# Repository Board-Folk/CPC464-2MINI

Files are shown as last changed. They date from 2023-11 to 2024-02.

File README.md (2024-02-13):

# CPC464-2MINI

A Mini CPC464

** Forever Work In Progress **

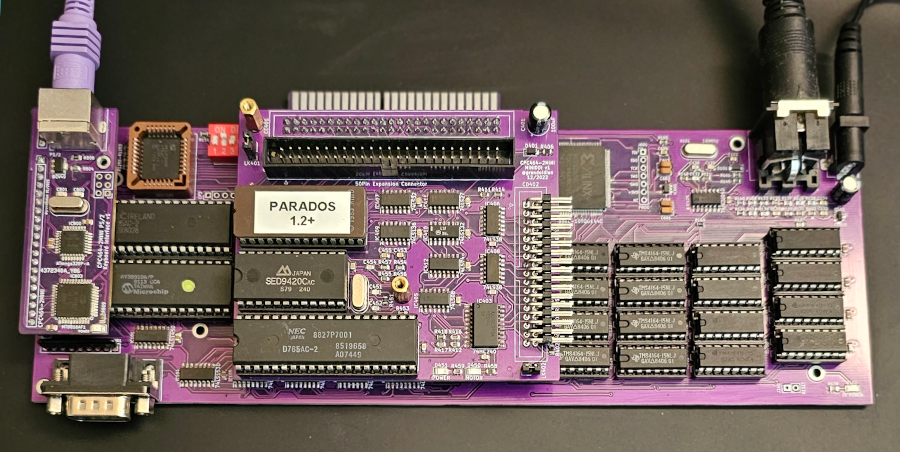
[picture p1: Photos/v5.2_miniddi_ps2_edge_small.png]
Built v5.2 Board with Edge Connector, PS/2 Interface and MINIDDI


A miniaturised version of Amstrad CPC464 second release with extensions. The main intention to try replace as much DIP with SMD as practically possible and have it as small as reasonably possible, with a standard board footprint that can later fit a 3D printed case that doesn't change between revisions. Latest versions, with everything on them, function as a 6128. This project is very much a private hobby project for now and is for fun and elements may lack any valid reason. It's been uploaded because of general interest.

More of the project may be dropped in here over time, kind of a place to sort out what's happened if you like, and what's working. There have been that many revisions/expansions it's been getting hard to keep track so it's nice to have a place. Things may be flagged as broken or untested where cautiously uploaded. 

## Revisions

The current version of the main board is v5.3, which uses the AMSGateArray Xilinx based gate array replacement linked to in the links section below. Thank you to all involved with that for this amazing project. Versions v4 and before require an original Amstrad 40010 or 40007 gate array (with adapter) for operation. Use of a 40007 somewhat impares operation especially regarding memory and other expansion compatiblity. Please see the readme file in each revisions folder for version specific information.

## Some Main Points

* Regulated 5V operation (centre terminal positive).
* The main board supports a full size original CPC464 Keyboard, **not** the later ones with the flat ribbon cables. An alternative PS/2 interface, which I expect most people will want to use is in the expansions folder.
* All releases still use 4164 RAM chips. Attempts at replacing these have so far failed due to the dual data bus (separate in and out pins are needed). Any help appreciated on this front, I can send schematics of my best guess so far which didn't work.
* All resistors and ceramic capacitors are 0805.
* Later revisions use PLCC32 instead of DIP28 for ROM due to space constraints.
* The v5 series board now also only supports the AY-3-8910 sound chip. Some earlier board supported the 8912, some both, the 8910 is much more readily available, also significantly cheaper. To note, you **can't** use an AY-3-8912 emulation board (well none that I've seen) with an Amstrad, they don't do the IO functions needed only sound.
* Some revisions of the board use a QFP44 Z80 not DIP40, including the latest revision, please check.
* Tape support changed for v5 on a different header needing an expansion card which hasn't been finished yet. Previous versions have a header compatible with the original 464 tape drive, and an adapter board for 3.5mm mono audio connections for a regular tape recorder/tapuino etc.
* There was a Mini-ITX version completed which included the disk interface (basically like a 6128), based on the pre-v5 boards in the Archive folder.
* As with original Amstrad CPCs of this generation, if you use the often more common A version AY-3-891x chip, e.g. AY-3-8910A you will need the SIP9 10K pullup resistor NR1 or your keyboard and joystick will not work correctly.
* All BOMs for now are just automatically generated iBOMs which only reflect the accuracy of the Kicad project they're from so be cautious.
* No, there's no HDMI port any of those other why didn't you things, feel free to add.

## Expansions

Expansion boards will be added over time. I'll try to place a big note in each readme which boards have not been tested. You'll probably want the Edge Connector, MINIDDI and PS/2 interfaces, but also check out the expansions folder.

Internal expansion boards stack vertically over a 2x25 pin header. Be warned, the rows for this are inverted from common secondary 6128 expansion cards that may already exist, though they typically need expansion adapter boards anyway for which there is one for this board. As things are at the moment each expansion card presents two headers for this to allow more options for stacking if you can't find the right socket/headers to stack directly. The primary expansions are:

* PS/2

An ATMEGA328/MT8816 based PS/2 adapter interface that mounts on the left of the board so you don't need an original keyboard.

* MINIEdge Edge Connector

It was decided that the main board wasn't going to include the original Amstrad edge connector as intended the expansions would be all neat and internal. The edge connector board solders on to the expansion connector on the base to provide the edge connector for traditional CPC expansions. This also has the virtue that the main board doesn't need ENIG, only this.

* MINIDDI

A version of the DDI-1 interface modified with the feelings of a 6128 and PPC640 to providing a 3.5" disk or Gotek drive interface. There's an adapter board for 3" drives.

** Check out the expansions folder for everything so far **

## Credits

Many thanks to Rob Taylor @peepouk and Chrissy @chris_jh with whom this project started, Richard Fry, Ian Stocks and the rest of the Board Folk Team. 
Special thanks to Noel Llopis for his amazing test ROM which has been invaluable for fixing buggy boards along the way.

## Links

  [AMSGateArray Gate Replacement Project](https://github.com/codedchip/AMSGateArray)<br>
  [Noel's Amstrad Diagnostics Test Suite](https://github.com/llopis/amstrad-diagnostics)

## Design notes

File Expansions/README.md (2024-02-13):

# CPC464-2MINI

CPC464-2MINI Expansions

* MINIEDGE

Edge connector for original expansion cards, for example the CPC Dandanator or whatever you might have.

* MINIPS/2

Atmega328 / MT8816 Based PS/2 Keyboard Adapter

* MINIDDI

3.5" Disk and Gotek Interface using the 765 disk controller and Epson SED. Standard PC floppy pinout. Adapter for 3" drives.

* MINIDOCK

Expansion to allow the installation of 6128 compatible expansion cards on the top of the system with additional 5V power injection.

* MINIRS232C

An updated version of the RS232C on a CPC464-2MINI Expansion board. Uses the MAX208 line driver / receiver with a 9 pin D-Sub instead

** On its way **

* MINIC2N

For the v5.3 board, a 9V system PSU and tape adapter to allow for the use of a Commodore C2N datasettes including both the C1530 and C1531 a well as 3.5mm Mic and Ear tape jacks for traditional cassette records and a header for an original CPC464 tape player as previously removed for v5. This works surprisingly well. Thanks to @PeepoUK for the idea.

** Untested and Unsorted **

* MINIUSIFACII

A USIFACII interface, though due to the chip shortage, this never got tested.

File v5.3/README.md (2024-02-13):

# CPC464-2MINI

CPC464-2MINI v5.3 Main Board

** Version 5 boards can't use an original Amstrad Gate array **

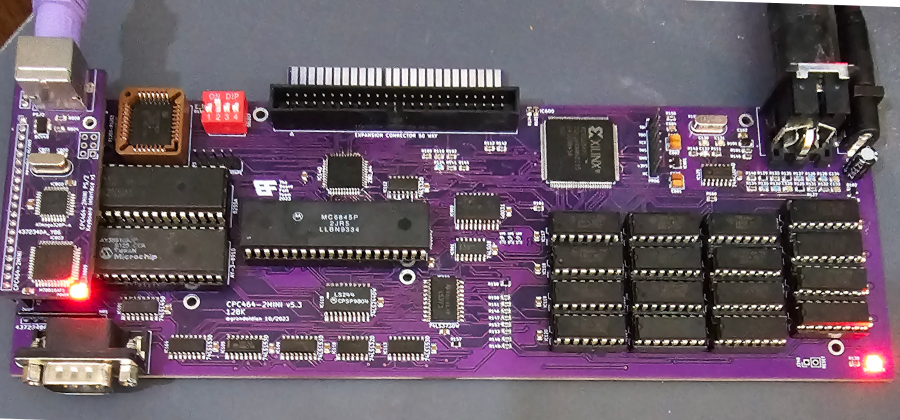
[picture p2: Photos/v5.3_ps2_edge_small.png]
Built v5.3 Main Board with PS/2 Keyboard Adapter


# Main points for this release

* AMSGateArray Xilinx based Gate Array. Needs skills.
* 128K RAM
* SMD 40031 GAL required for 128K operation
* QFP44 Z80 CPU
* AY-3-8910 Sound/IO Only
* PLCC32 ROM with switch selectable banking

# BOM

iBOM can be found in BOM folder.

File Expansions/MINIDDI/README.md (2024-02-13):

# MINIDDI

3.5" Disk and Gotek Interface using the 765 disk controller and Epson SED.

# Main points 

* Based on the DDI-1 with modifications for the Epson SED (as found in the 6128).
* This works with standard 3.5" PC Drives, and Goteks having borrowed slight changes from the PPC640.
* Adapter in the Extras folder for use with 3" drives.
* This hasn't really changed since the first release since it works so well. Might need a tidy up.
* More information to follow

# BOM

iBOM can be found in BOM folder.

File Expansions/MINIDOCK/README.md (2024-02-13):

# CPC464-2MINI Mini Dock

Docking board to allow the connection of vertical 6128 expansions on top.

# Main points 

* Only really proven with 6128 RAM Expansions
* Straight means same as the main board expansion pinout, inverted for 6128 expansion cards.
* Also provides additional power injection which may be required.
* Needs more testing.

# BOM

iBOM can be found in BOM folder.

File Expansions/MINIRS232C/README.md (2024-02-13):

# CPC464-2MINIRS232C v2

A CPC464-2MINI version of the original Amstrad RS232C adapter modified with an updated line driver / receiver and 9 pin D-Sub. Needs an original or Honeysoft Commstar ROM to operate.

# Main points 

* It uses an Z80 DART not the SIO/2
* The line driver / receiver is a MAX208 or compatible
* There was an original version with the original line driver and receiver which needs a voltage level converter which I may upload if needed. It's just easier to use the MAX208 version instead.
* More information to follow.

# BOM

iBOM can be found in BOM folder.

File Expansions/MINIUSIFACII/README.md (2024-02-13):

# CPC464-2MINIUSIFACII

A USIFACII board but due to the chip shortage, this never got tested.

# BOM

iBOM can be found in BOM folder.

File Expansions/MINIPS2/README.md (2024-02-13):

# MINIPS/2

Atmega328 / MT8816 Based PS/2 Adapter for the CPC464-2MINI

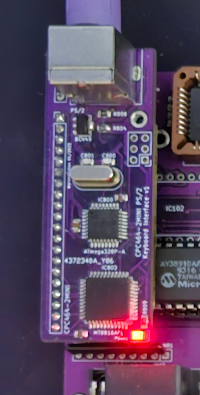
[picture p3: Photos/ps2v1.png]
Built PS/2 Interface


# Main points 

* Arduino Code found in the Arduino Folder. This needs uploading to the ATMega328.
* Print Screen pulls down !BUS to reset the system
* More notes to follow

# BOM

iBOM can be found in BOM folder.

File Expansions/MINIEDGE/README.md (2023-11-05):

# CPC464-2MINI-EDGE

Edge connector for original expansion cards, for example the CPC Dandanator or whatever you might have.

# Main points 

* This solders onto the base of the expansion header on the main board. Make sure you have long enough pins!
* This hasn't change since day dot.
* You might want to get this printed with ENIG.

# BOM

* There are no components on this board.

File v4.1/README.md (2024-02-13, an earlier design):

# CPC464-2MINI

CPC464-2MINI v4.1 Main Board

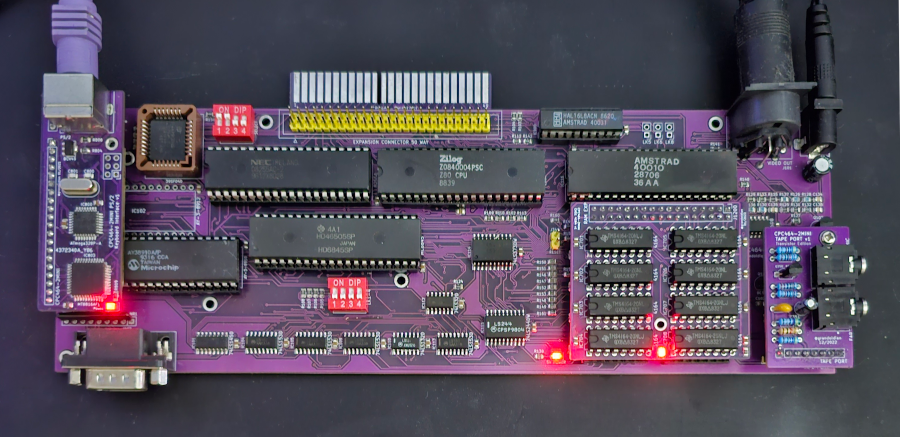
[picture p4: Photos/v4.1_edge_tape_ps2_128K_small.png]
Built CPC464-2MINI v4.1 Board


# Main points for this release

* Requires original Gate Array, 40010 or 40007 (with adapter). 40007 use impares operation.
* 128K RAM with upper 64K on expansion board
* 40031 DIP20 GAL required for 128K operation
* DIP40 Z80 CPU
* Both AY-3-8912 and AY-3-8910 Sound/IO chip sockets
* PLCC32 ROM with switch selectable banking
* DIP switch for ROM brand selection
* Original Tape Drive support, with adapter for 3.5mm mono audio connections

# BOM

iBOM can be found in BOM folder.

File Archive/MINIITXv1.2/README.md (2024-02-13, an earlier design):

# CPC464-2MINIITX v1.2

This ended up as a side project to try combine a few things, and well, to see if it fits. This last release works well anyway. It needs a 40010 though or Xilinx with an adapter board, which can sit over the RAM area.

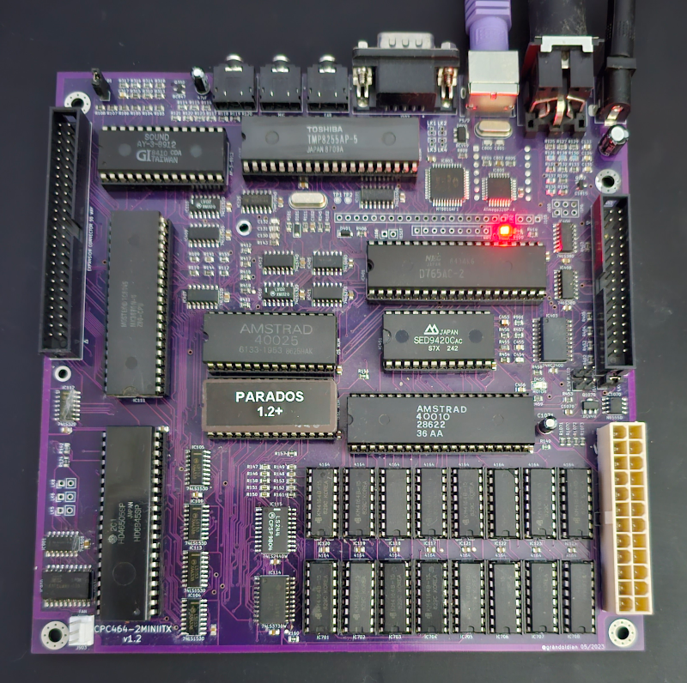
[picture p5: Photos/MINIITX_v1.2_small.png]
Built CPC464-2 MiniITX v1.2 Board


# Includes

* Disk Interface
* PS/2 Interface
* PIN headers for the other USB Keyboard project (which uses a SEEDUINO) that isn't published anywhere yet.
* Regular CPC464-2MINIITX Expansion slot, but sideways

# Main points 

* DIP40 Z80
* DIP28 ROMs
* AY-3-8912 Sound / IO
* 128K on board requiring the SMD 40031 GAL.
* ATX Power and Switch Latch or 5V DC Jack
* 3.5mm Mono Audio Tape Interface

# BOM

iBOM can be found in BOM folder.

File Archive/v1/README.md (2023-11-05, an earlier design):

# CPC464-2MINI v1

Uploaded for posterity and reference. The original second version of the CPC 464 on a board in the MINI size. 64K Only.

Please see the CPC-40007Adapter board in the v4 Extras folder if you want to use an original Amstrad 40007 Gate Array with this.

# BOM

iBOM can be found in BOM folder.

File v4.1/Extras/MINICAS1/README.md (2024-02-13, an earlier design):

# CPC464-2MINICAS1

Upper 64K Board for the CPC464-2MINI v4

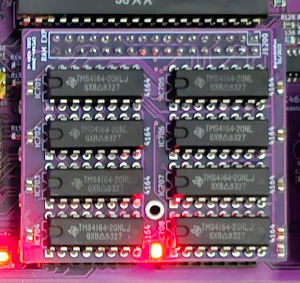
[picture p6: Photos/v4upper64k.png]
Upper 64K of RAM for v4.1


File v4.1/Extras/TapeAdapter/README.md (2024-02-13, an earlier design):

# CPC464-2MINI Tape Adapter

Tape Adapter for v4 and below revision CPC464-2MINI boards. This does not fit v5, that's to follow.

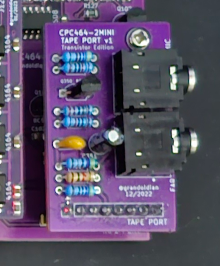
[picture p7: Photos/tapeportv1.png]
Built Tape Adapter


# Main points 

* This version uses a transistor and slight current limiting to allow you to plug in a standard tape recorder or Tapduino. It mounts on the tape header to the south east of the board instead of an original CPC464 tape player.

# BOM

iBOM can be found in BOM folder.

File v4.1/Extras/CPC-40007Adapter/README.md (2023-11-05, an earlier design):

# CPC-40007Adapter

An adapter to plug an Amstrad 40007 Gate Array in to a 40010 Socket. It's not a great idea, but if you're stuck.

This is nothing to do with the CPC464-2MINI v5 board, which can't use an original gate array.

# Main points 

* There are many things fundamentally flawed in doing this, including broken addressing, for example it won't boot with a Dandanator and 128K.
* It might need long pins to get above other components on later CPC464-2MINI boards.
* Due to the old Ferranti process, this requires a second voltage and generates some heat.
* There might be some fundamental flaw that I've missed that causes bad things to happen.
* It uses an LM1117 instead of resistors for the second voltage required.

# BOM

iBOM can be found in BOM folder.

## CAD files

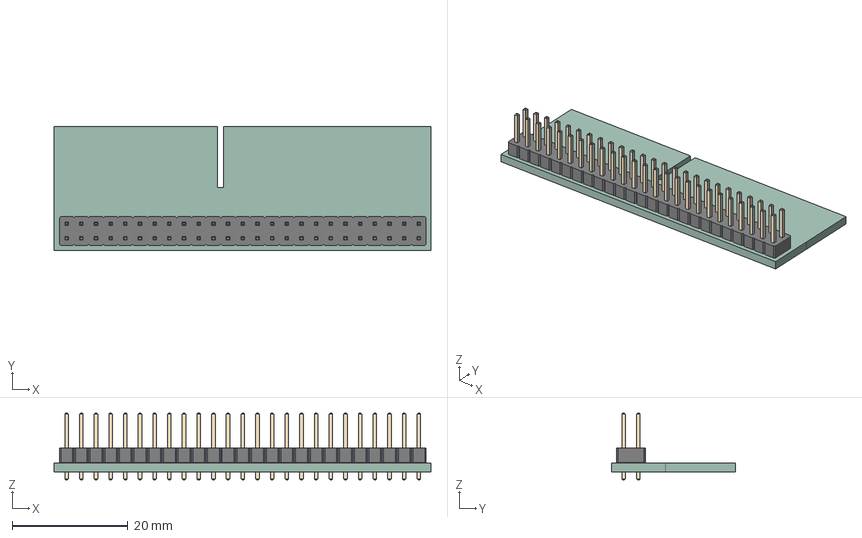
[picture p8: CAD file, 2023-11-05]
Expansions/MINIEDGE/Kicad/CPC464-2MINI-EDGE.step
65.2 x 21.4 x 11.5 mm
CPC464-2MINI-EDGE PCB

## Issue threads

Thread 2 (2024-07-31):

Sound problem and a few other problems.

HtmlBosss, 2024-07-31:
Hello, I assembled a few PCBs in version 5.3.

1) I have a problem with AY sound.

I use AY-3-8910A or YM2149F but I can't get any sound. I always hear noise (literally noise) on the J103 stereo output after starting any game or software. Do you have the same?
Problem with sound and a few other problems.

2) How do you have the jumpers set on resistors R185-R188?

3) Can I replace transistor Q102 (C1815) with another transistor that has similar pinouts and parameters?

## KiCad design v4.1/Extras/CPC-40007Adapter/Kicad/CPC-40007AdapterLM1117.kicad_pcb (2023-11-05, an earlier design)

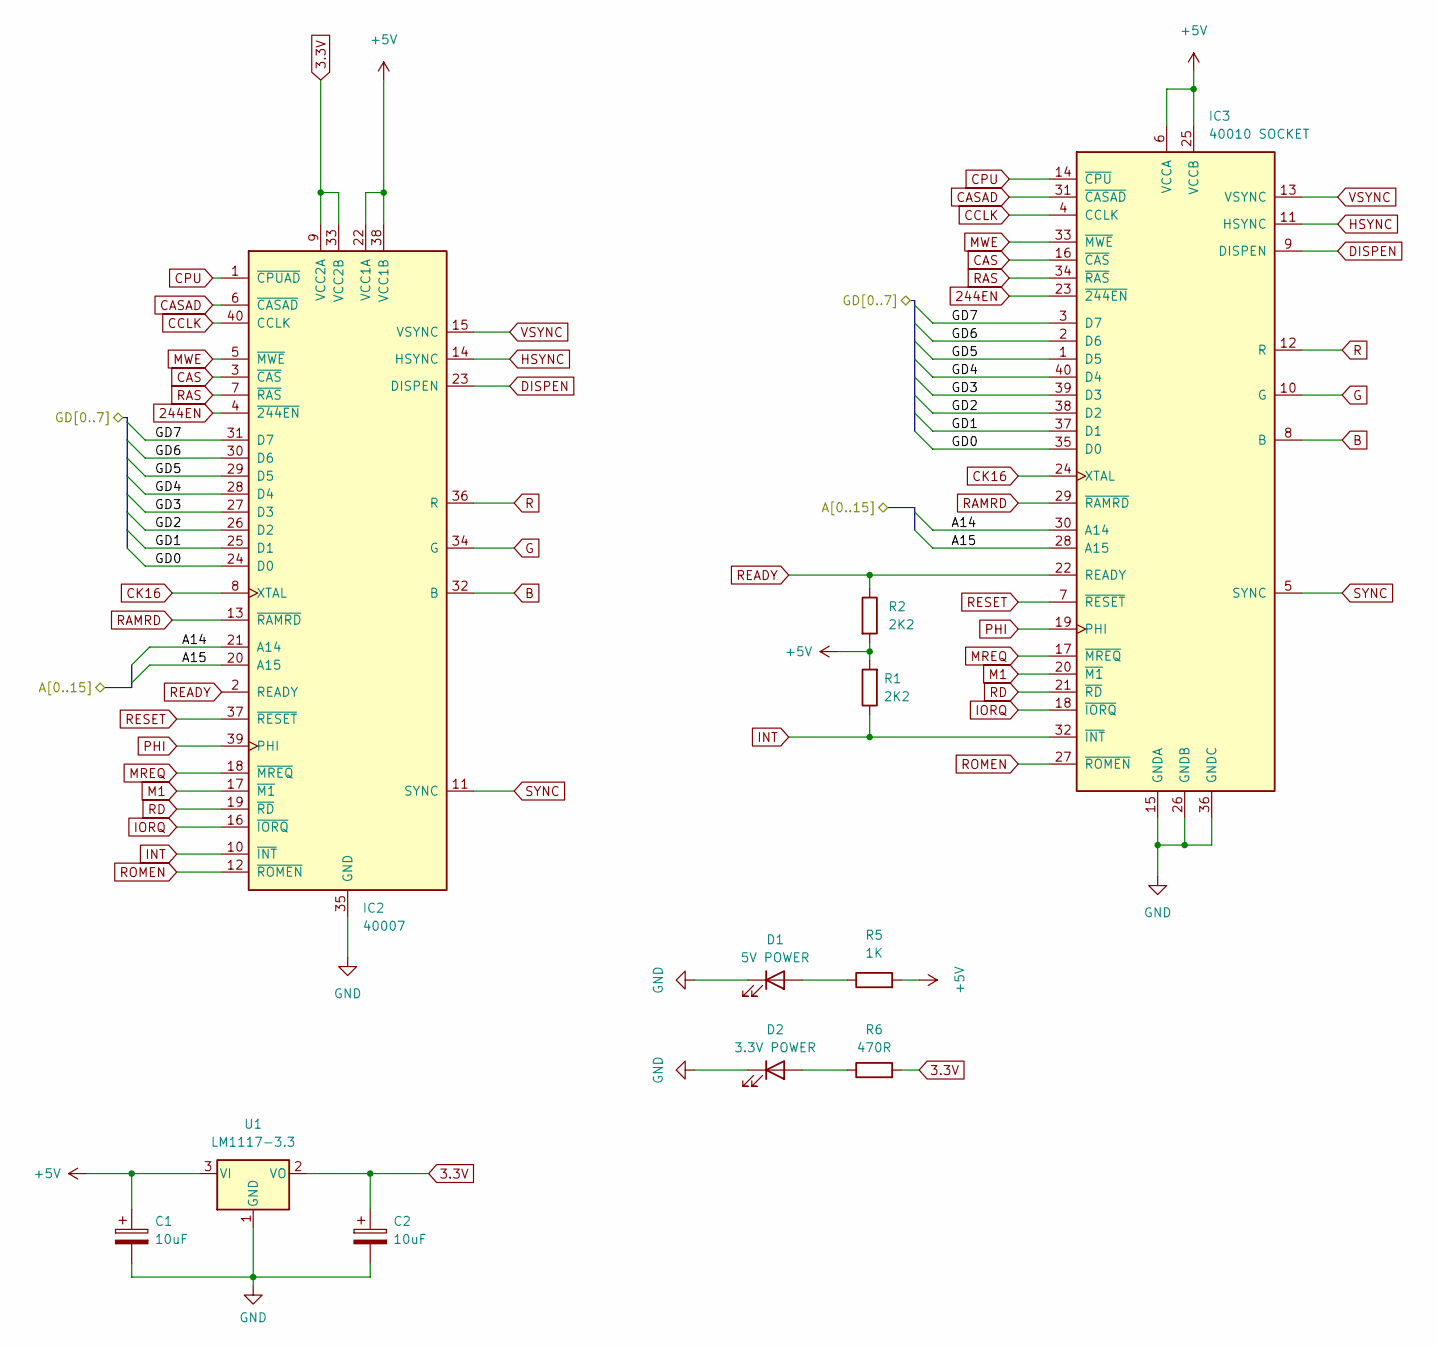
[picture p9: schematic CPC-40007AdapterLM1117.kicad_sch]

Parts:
C1, C2: 10uF; CP_EIA-3216-18_Kemet-A
D1: 5V POWER; LED_1206_3216Metric
D2: 3.3V POWER; LED_1206_3216Metric
IC2: 40007; DIP-40_W15.24mm_Socket_LongPads
IC3: 40010 SOCKET; 40010_Plug
R1, R2: 2K2; R_0805_2012Metric
R5: 1K; R_0805_2012Metric
R6: 470R; R_0805_2012Metric
U1: LM1117-3.3; SOT-223-3_TabPin2

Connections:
3.3V: C2.1, IC2.9 (VCC2A), IC2.33 (VCC2B), R6.2, U1.2 (VO)
244EN: IC2.4 (~244EN), IC3.23 (~244EN)
+5V: C1.1, IC2.22 (VCC1A), IC2.38 (VCC1B), IC3.6 (VCCA), IC3.25 (VCCB), R1.2, R2.2, R5.2, U1.3 (VI)
/A14: IC2.21 (A14), IC3.30 (A14)
/A15: IC2.20 (A15), IC3.28 (A15)
/GD0: IC2.24 (D0), IC3.35 (D0)
/GD1: IC2.25 (D1), IC3.37 (D1)
/GD2: IC2.26 (D2), IC3.38 (D2)
/GD3: IC2.27 (D3), IC3.39 (D3)
/GD4: IC2.28 (D4), IC3.40 (D4)
/GD5: IC2.29 (D5), IC3.1 (D5)
/GD6: IC2.30 (D6), IC3.2 (D6)
/GD7: IC2.31 (D7), IC3.3 (D7)
B: IC2.32 (B), IC3.8 (B)
CAS: IC2.3 (~CAS), IC3.16 (~CAS)
CASAD: IC2.6 (~CASAD), IC3.31 (~CASAD)
CCLK: IC2.40 (CCLK), IC3.4 (CCLK)
CK16: IC2.8 (XTAL), IC3.24 (XTAL)
CPU: IC2.1 (~CPUAD), IC3.14 (~CPU)
DISPEN: IC2.23 (DISPEN), IC3.9 (DISPEN)
G: IC2.34 (G), IC3.10 (G)
GND: C1.2, C2.2, D1.1 (K), D2.1 (K), IC2.35 (GND), IC3.15 (GNDA), IC3.26 (GNDB), IC3.36 (GNDC), U1.1 (GND)
HSYNC: IC2.14 (HSYNC), IC3.11 (HSYNC)
INT: IC2.10 (~INT), IC3.32 (~INT), R1.1
IORQ: IC2.16 (~IORQ), IC3.18 (~IORQ)
M1: IC2.17 (~M1), IC3.20 (~M1)
MREQ: IC2.18 (~MREQ), IC3.17 (~MREQ)
MWE: IC2.5 (~MWE), IC3.33 (~MWE)
unnamed: D1.2 (A), R5.1
unnamed: D2.2 (A), R6.1
PHI: IC2.39 (PHI), IC3.19 (PHI)
R: IC2.36 (R), IC3.12 (R)
RAMRD: IC2.13 (~RAMRD), IC3.29 (~RAMRD)
RAS: IC2.7 (~RAS), IC3.34 (~RAS)
RD: IC2.19 (~RD), IC3.21 (~RD)
READY: IC2.2 (READY), IC3.22 (READY), R2.1
RESET: IC2.37 (~RESET), IC3.7 (~RESET)
ROMEN: IC2.12 (~ROMEN), IC3.27 (~ROMEN)
SYNC: IC2.11 (SYNC), IC3.5 (SYNC)
VSYNC: IC2.15 (VSYNC), IC3.13 (VSYNC)

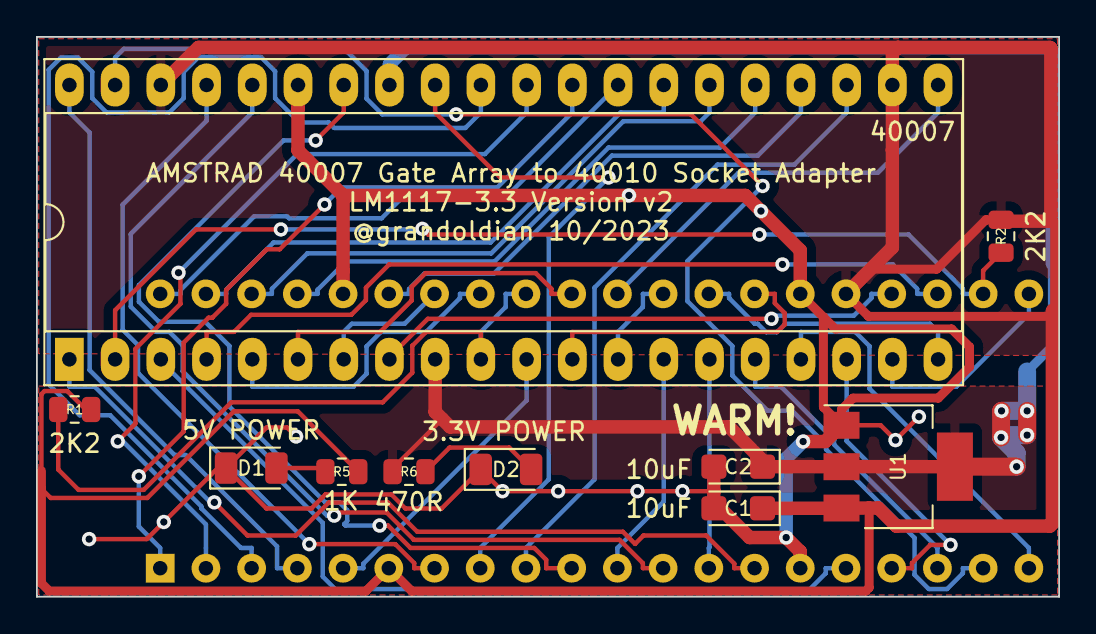
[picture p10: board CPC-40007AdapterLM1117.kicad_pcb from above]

Board: 2 copper layers, 56.8 x 31.1 mm, 11 parts (0 on the bottom side), 40 nets.

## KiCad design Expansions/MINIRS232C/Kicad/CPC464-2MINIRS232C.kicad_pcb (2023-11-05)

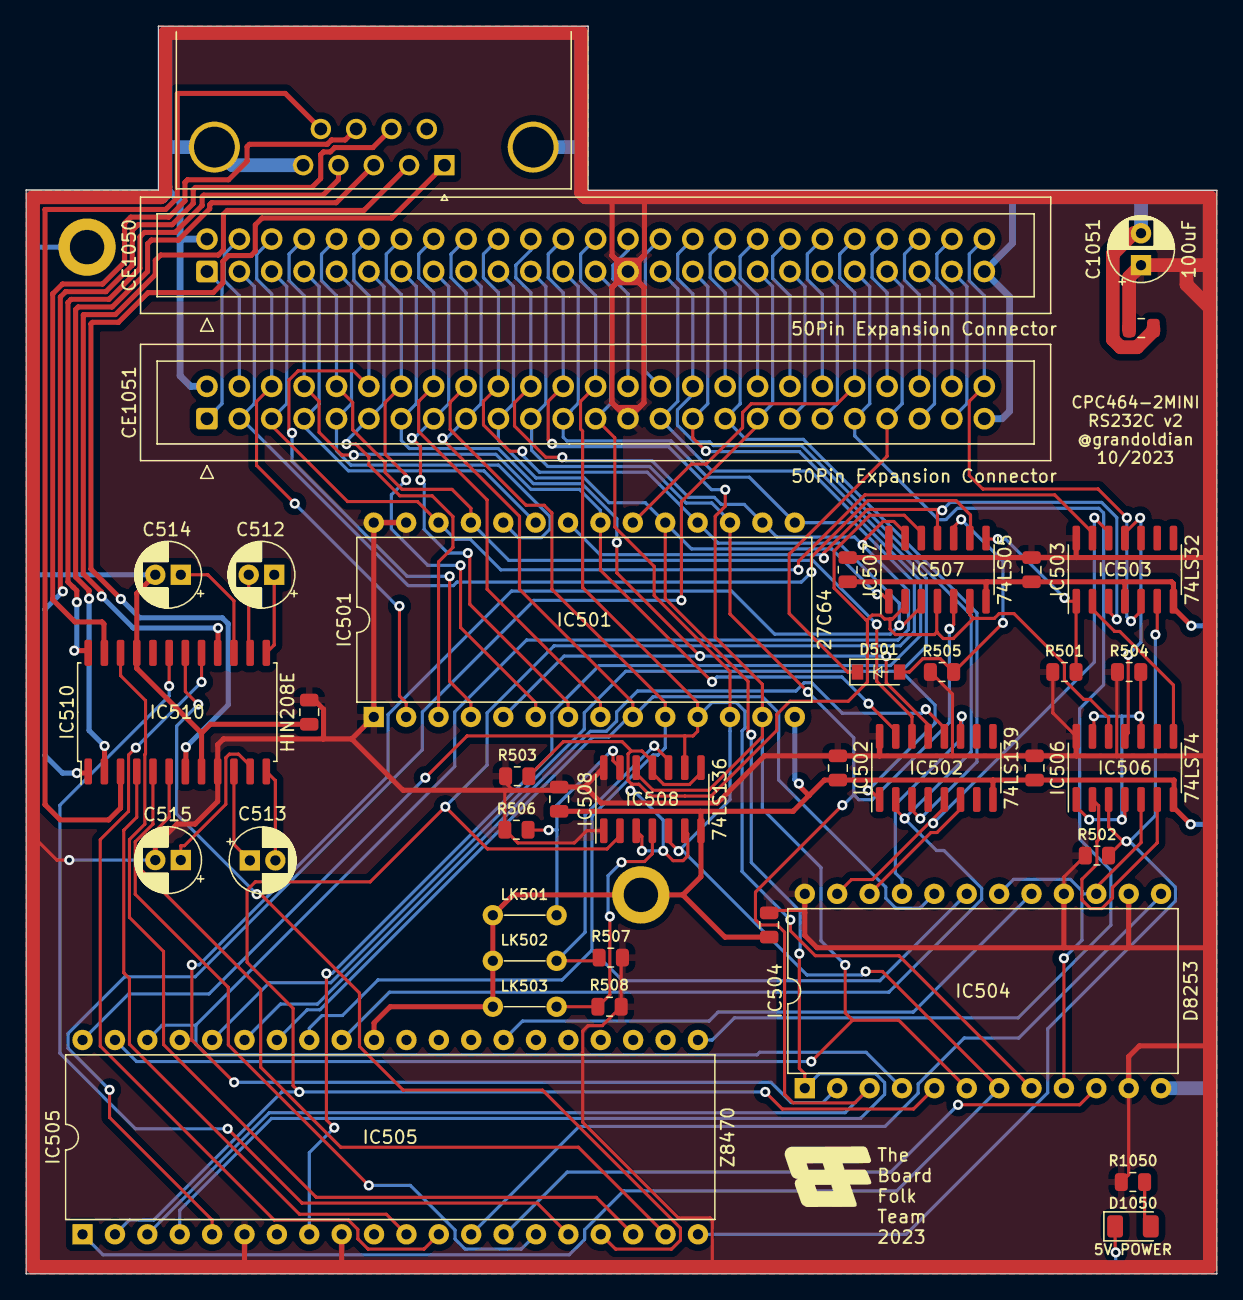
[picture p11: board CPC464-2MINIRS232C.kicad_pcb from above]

Board: 2 copper layers, 93.4 x 97.9 mm, 42 parts (0 on the bottom side), 90 nets.

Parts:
C502, C503, C504, C505, C506, C507, C508, C1050: 100nF; C_0805_2012Metric
C512, C513, C514, C515: 0.1uF; CP_Radial_D5.0mm_P2.00mm
C1051: 100uF; CP_Radial_D5.0mm_P2.50mm
CE1050, CE1051: 50Pin Expansion Connector; EXPANSION_IDC_ANONYMISED
D501: 1N4148; D101
D1050: 5V POWER; LED_1206_3216Metric
G1: Board Folk Logo; BF8
H1, H7: MountingHole; MountingHole_2.7mm_M2.5_ISO14580_Pad
IC501: 27C64; DIP-28_W15.24mm
IC502: 74LS139; SOIC-16_3.9x9.9mm_P1.27mm
IC503: 74LS32; SOIC-14_3.9x8.7mm_P1.27mm
IC504: D8253; DIP-24_W15.24mm
IC505: Z8470; DIP-40_W15.24mm
IC506: 74LS74; SOIC-14_3.9x8.7mm_P1.27mm
IC507: 74LS05; SOIC-14_3.9x8.7mm_P1.27mm
IC508: 74LS136; SOIC-14_3.9x8.7mm_P1.27mm
IC510: HIN208E; SOIC-24W_7.5x15.4mm_P1.27mm
LK501, LK502, LK503: Capacitor
PL505: DB9; DSUB-9_Male_Horizontal_P2.77x2.84mm_EdgePinOffset7.70mm_Hou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
R501, R503, R504, R1050: 1K; R_0805_2012Metric
R502, R505: 670R; R_0805_2012Metric
R506, R507, R508: 10K; R_0805_2012Metric

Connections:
+5V: C502.1, C503.1, C504.1, C505.1, C506.1, C507.1, C508.1, C515.2, C1050.1, C1051.1, CE1050.27, CE1051.27, IC501.1 (VPP), IC501.27 (~PGM), IC501.28 (VCC), IC502.16 (VCC), IC503.14 (VCC), IC504.11 (GATE0), IC504.14 (GATE1), IC504.16 (GATE2), IC504.24 (VCC), IC505.6 (IEI), IC505.9 (VCC), IC506.14 (VCC), IC507.14 (VCC), IC508.1, IC508.14 (VCC), IC510.9 (VCC), R501.1, R502.1, R503.1, R504.1, R505.1, R506.1, R507.1, R508.1, R1050.2
/AMSRS232C SM Edited/A0: CE1050.18, CE1051.18, IC501.10 (A0), IC504.19 (A0), IC505.33 (C/~D)
/AMSRS232C SM Edited/A1: CE1050.17, CE1051.17, IC501.9 (A1), IC504.20 (A1), IC505.34 (B/~A)
/AMSRS232C SM Edited/A2: CE1050.16, CE1051.16, IC501.8 (A2)
/AMSRS232C SM Edited/A3: CE1050.15, CE1051.15, IC501.7 (A3)
/AMSRS232C SM Edited/A4: CE1050.14, CE1051.14, IC501.6 (A4)
/AMSRS232C SM Edited/A5: CE1050.13, CE1051.13, IC501.5 (A5), IC502.13 (A1)
/AMSRS232C SM Edited/A6: CE1050.12, CE1051.12, IC501.4 (A6)
/AMSRS232C SM Edited/A7: CE1050.11, CE1051.11, IC501.3 (A7)
/AMSRS232C SM Edited/A8: CE1050.10, CE1051.10, IC501.25 (A8), IC502.14 (A0)
/AMSRS232C SM Edited/A9: CE1050.9, CE1051.9, IC501.24 (A9)
/AMSRS232C SM Edited/A10: CE1050.8, CE1051.8, IC501.21 (A10), IC502.15 (E)
/AMSRS232C SM Edited/A11: CE1050.7, CE1051.7, IC501.23 (A11)
/AMSRS232C SM Edited/A12: CE1050.6, CE1051.6, IC501.2 (A12)
/AMSRS232C SM Edited/A13: CE1050.5, CE1051.5, IC501.26 (A13), IC503.13
/AMSRS232C SM Edited/A14: CE1050.4, CE1051.4
/AMSRS232C SM Edited/A15: CE1050.3, CE1051.3, IC507.9
/AMSRS232C SM Edited/CTS_IN: IC505.18 (~CTSA), IC510.22 (R3OUT)
/AMSRS232C SM Edited/D0: CE1050.26, CE1051.26, IC501.11 (D0), IC504.8 (D0), IC505.40 (D0), IC508.9
/AMSRS232C SM Edited/D1: CE1050.25, CE1051.25, IC501.12 (D1), IC504.7 (D1), IC505.1 (D1), IC508.5
/AMSRS232C SM Edited/D2: CE1050.24, CE1051.24, IC501.13 (D2), IC504.6 (D2), IC505.39 (D2), IC508.12
/AMSRS232C SM Edited/D3: CE1050.23, CE1051.23, IC501.15 (D3), IC504.5 (D3), IC505.2 (D3), IC508.2
/AMSRS232C SM Edited/D4: CE1050.22, CE1051.22, IC501.16 (D4), IC504.4 (D4), IC505.38 (D4), IC507.13
/AMSRS232C SM Edited/D5: CE1050.21, CE1051.21, IC501.17 (D5), IC504.3 (D5), IC505.3 (D5), IC507.5
/AMSRS232C SM Edited/D6: CE1050.20, CE1051.20, IC501.18 (D6), IC504.2 (D6), IC505.37 (D6), IC507.3
/AMSRS232C SM Edited/D7: CE1050.19, CE1051.19, IC501.19 (D7), IC504.1 (D7), IC505.4 (D7), IC507.1
/AMSRS232C SM Edited/DCD_IN: IC505.19 (~DCDA), IC510.6 (R1OUT)
/AMSRS232C SM Edited/DTR_OUT: IC505.16 (~DTRA), IC510.19 (T3IN)
/AMSRS232C SM Edited/RI_IN: IC505.11 (~RIA), IC510.4 (R2OUT)
/AMSRS232C SM Edited/RTS_OUT: IC505.17 (~RTSA), IC510.18 (T2IN)
/AMSRS232C SM Edited/RX_OUT: IC505.15 (TxDA), IC510.5 (T1IN)
/AMSRS232C SM Edited/TX_IN: IC505.12 (RxDA), IC510.17 (R4OUT)
A100: CE1050.50, CE1051.50, IC503.5
BUS: CE1050.40, CE1051.40
BUSAK: CE1050.38, CE1051.38
BUSRQ: CE1050.37, CE1051.37
CURSOR: CE1050.46, CE1051.46
DCLK: IC503.6, IC505.20 (CLK), IC506.3 (C), R502.2
DSEL: IC502.12 (O0), IC505.35 (~CE)
EXP: CE1050.48, CE1051.48
GND: C502.2, C503.2, C504.2, C505.2, C506.2, C507.2, C508.2, C514.2, C1050.2, C1051.2, CE1050.2, CE1050.49, CE1051.2, CE1051.49, D1050.1 (K), H1.1, H7.1, IC501.14 (GND), IC502.8 (GND), IC503.4, IC503.7 (GND), IC504.12 (GND), IC505.31 (GND), IC506.7 (GND), IC507.7 (GND), IC508.7 (GND), IC510.8 (GND), IC510.21 (T4IN), LK501.2, LK502.2, LK503.2, PL505.0 (PAD), PL505.5
HALT: CE1050.34, CE1051.34
INT: CE1050.35, CE1051.35, IC505.5 (~INT)
IORQ: CE1050.31, CE1051.31, IC502.1 (E), IC505.36 (~IORQ)
LPEN: CE1050.47, CE1051.47
M1: CE1050.29, CE1051.29, IC505.8 (~M1)
MREQ: CE1050.28, CE1051.28
NMI: CE1050.36, CE1051.36
unnamed: D501.2 (A), IC507.10, R505.2
unnamed: D1050.2 (A), R1050.1
unnamed: IC502.11 (O1), IC504.21 (~CS)
unnamed: IC503.1, IC507.8, R501.2
unnamed: IC504.9 (CLK0), IC504.15 (CLK1), IC504.18 (CLK2), IC506.5 (Q)
unnamed: IC504.10 (OUT0), IC505.14 (~TxCA)
unnamed: IC504.13 (OUT1), IC505.13 (~RxCA)
unnamed: IC504.17 (OUT2), IC505.27 (~RxTxCB)
unnamed: IC506.2 (D), IC506.6 (~Q)
unnamed: IC506.1 (~R), IC506.4 (~S), IC506.10 (~S), IC506.13 (~R), R504.2
unnamed: IC503.11, IC506.11 (C)
unnamed: IC503.2, IC506.8 (~Q)
unnamed: C513.1, IC510.10 (C1+)
unnamed: C513.2, IC510.12 (C1-)
unnamed: C512.1, IC510.13 (C2+)
unnamed: C512.2, IC510.14 (C2-)
unnamed: C515.1, IC510.11 (V+)
unnamed: C514.1, IC510.15 (V-)
unnamed: IC508.13, LK501.1, R506.2
unnamed: IC508.10, LK502.1, R507.2
unnamed: IC508.4, LK503.1, R508.2
ODDEN: IC506.12 (D), IC507.2, IC507.4, IC507.6, IC507.12, IC508.3, IC508.6, IC508.8, IC508.11, R503.2
RAMDIS: CE1050.45, CE1051.45
RAMRD: CE1050.44, CE1051.44
RD: CE1050.32, CE1051.32, IC502.2 (A0), IC505.32 (~RD)
READY: CE1050.39, CE1051.39
RESET: CE1050.41, CE1051.41, IC505.21 (~RESET)
RFSH: CE1050.30, CE1051.30
ROMDIS: CE1050.43, CE1051.43, D501.1 (K)
ROMEN: CE1050.42, CE1051.42, IC501.20 (~CE)
RS_CTS: IC510.23 (R3IN), PL505.8
RS_DCD: IC510.7 (R1IN), PL505.1
RS_DTR: IC510.24 (T3OUT), PL505.4
RS_RI: IC510.3 (R2IN), PL505.9
RS_RTS: IC510.1 (T2OUT), PL505.7
RS_RX: IC510.2 (T1OUT), PL505.3
RS_TX: IC510.16 (R4IN), PL505.2
SOUND: CE1050.1, CE1051.1
WR: CE1050.33, CE1051.33, IC502.3 (A1)
~RARD: IC502.6 (O2), IC504.22 (~RD)
~RAWR: IC502.5 (O1), IC503.12, IC504.23 (~WR)
~ROMOE: IC501.22 (~OE), IC503.3, IC507.11

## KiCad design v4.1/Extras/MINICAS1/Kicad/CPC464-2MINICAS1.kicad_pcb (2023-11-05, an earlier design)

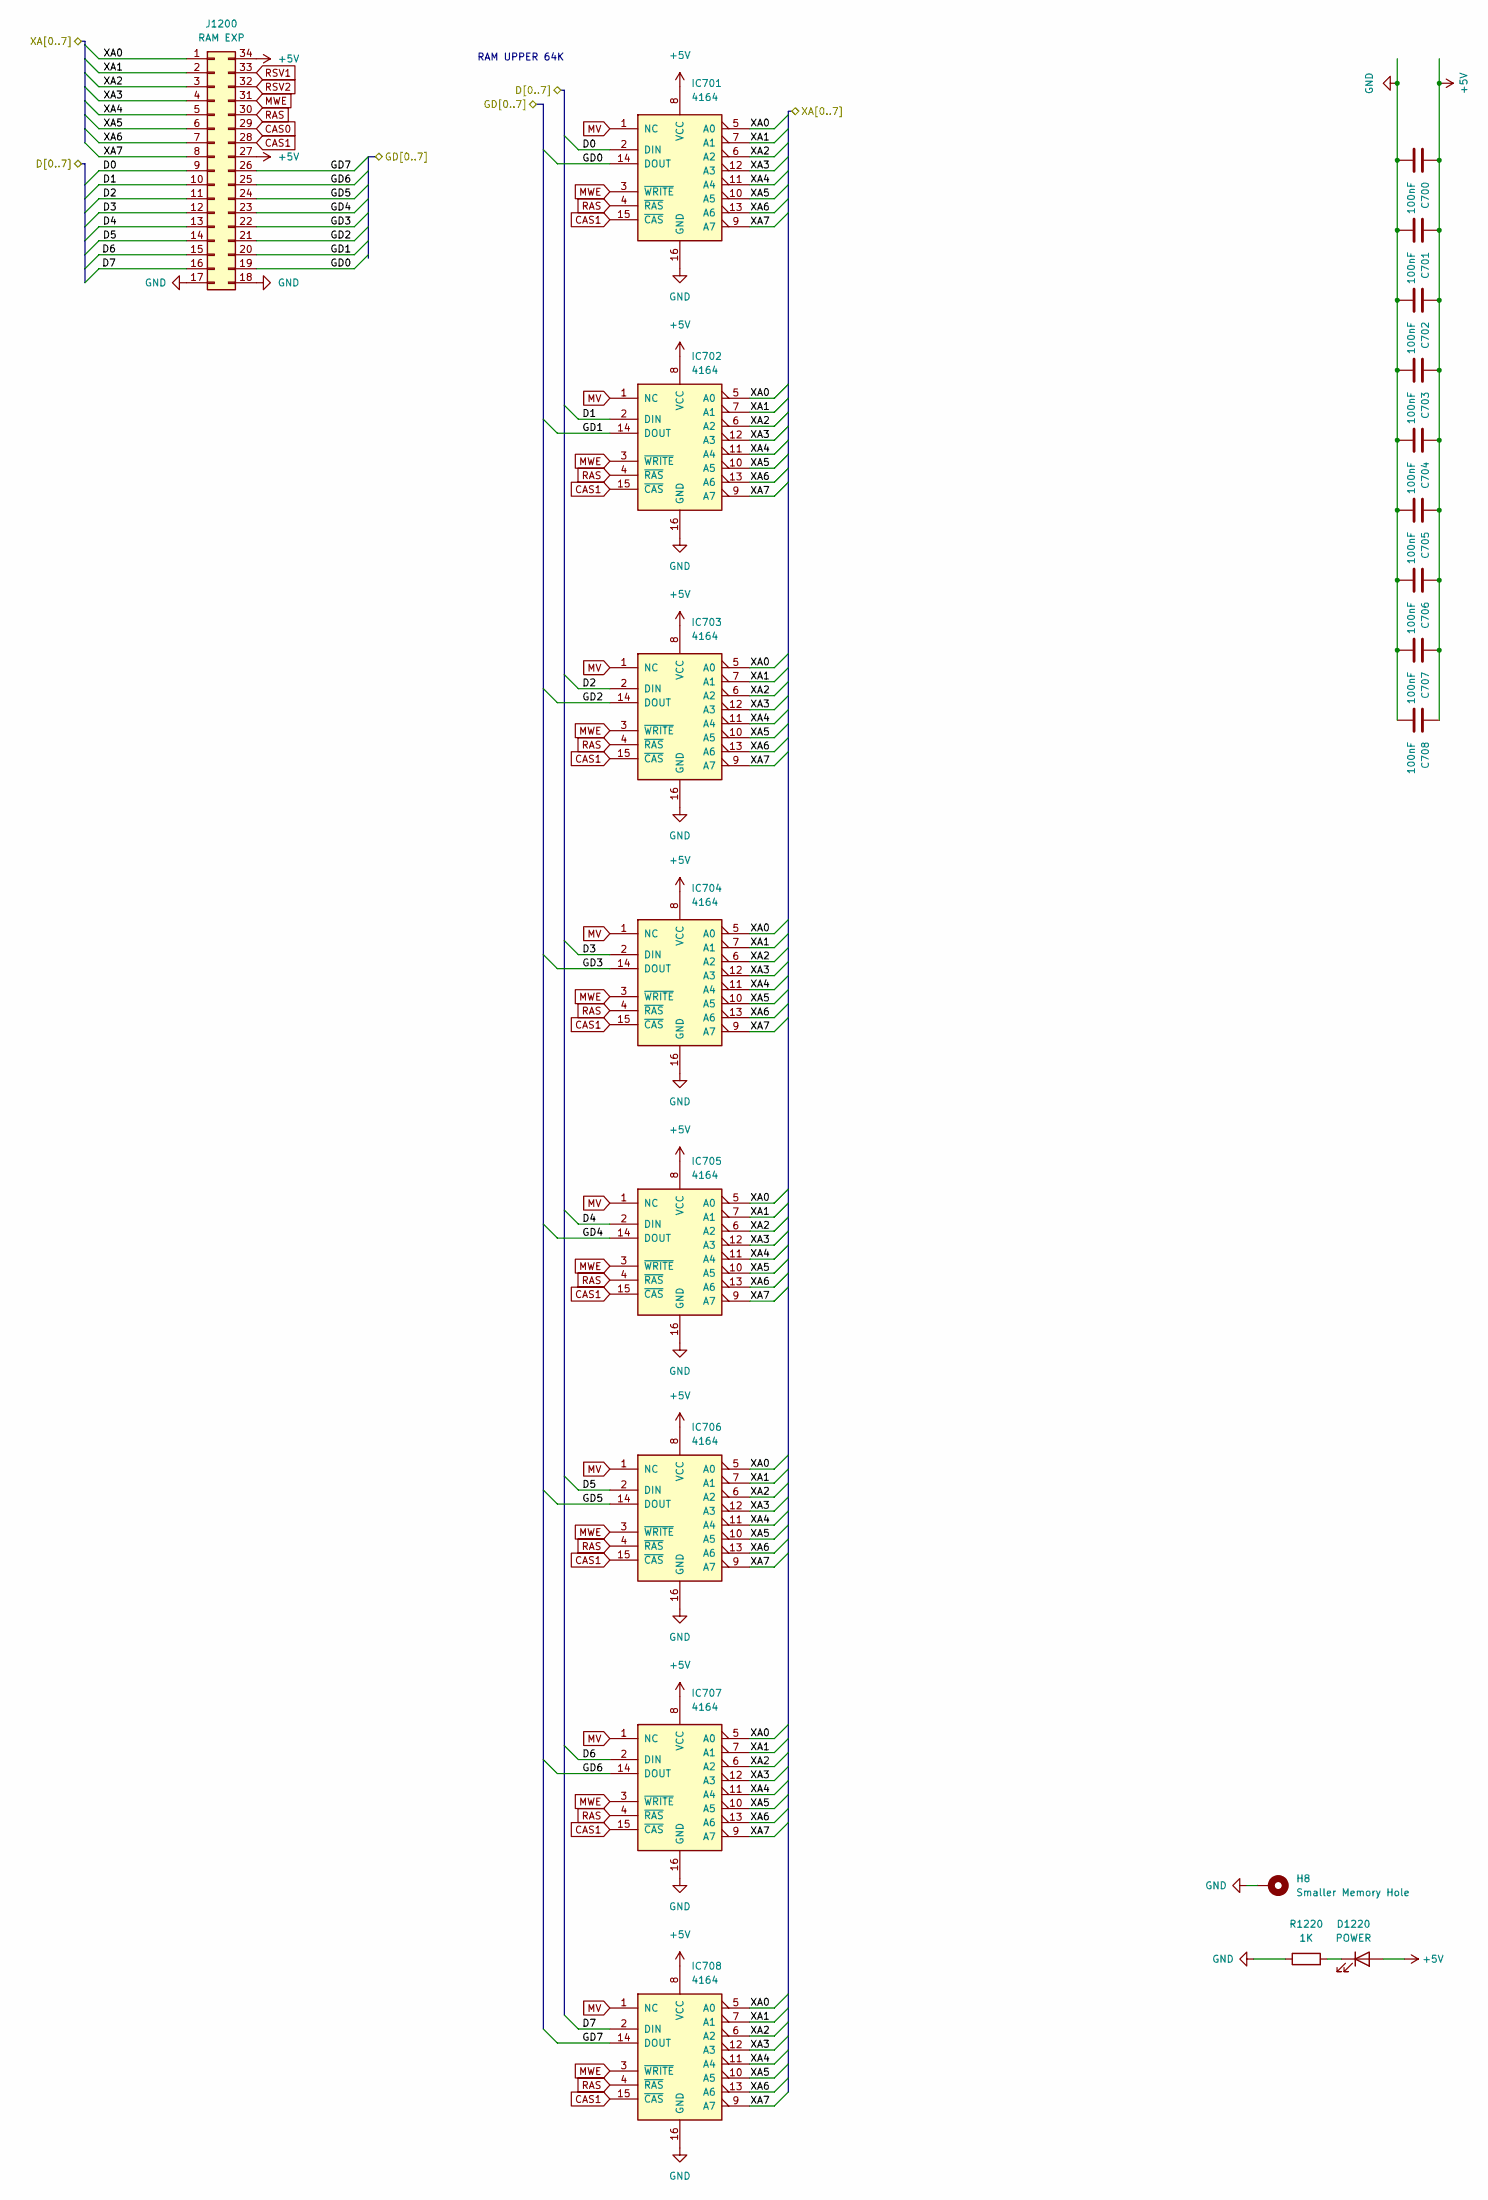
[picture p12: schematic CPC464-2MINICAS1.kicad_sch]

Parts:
C700, C701, C702, C703, C704, C705, C706, C707, C708: 100nF; C_0805_2012Metric; LCSC C49678
D1220: POWER; LED_1206_3216Metric
H8: Smaller Memory Hole; MountingHole_2.2mm_M2_DIN965_Pad
IC701, IC702, IC703, IC704, IC705, IC706, IC707, IC708: 4164; DIP-16_W7.62mm
J1200: RAM EXP; PinHeader_2x17_P2.54mm_Vertical
R1220: 1K; R_0805_2012Metric

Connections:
+5V: C700.1, C701.1, C702.1, C703.1, C704.1, C705.1, C706.1, C707.1, C708.1, D1220.2 (A), IC701.8 (VCC), IC702.8 (VCC), IC703.8 (VCC), IC704.8 (VCC), IC705.8 (VCC), IC706.8 (VCC), IC707.8 (VCC), IC708.8 (VCC), J1200.27, J1200.34
/D0: IC701.2 (DIN), J1200.9
/D1: IC702.2 (DIN), J1200.10
/D2: IC703.2 (DIN), J1200.11
/D3: IC704.2 (DIN), J1200.12
/D4: IC705.2 (DIN), J1200.13
/D5: IC706.2 (DIN), J1200.14
/D6: IC707.2 (DIN), J1200.15
/D7: IC708.2 (DIN), J1200.16
/GD0: IC701.14 (DOUT), J1200.19
/GD1: IC702.14 (DOUT), J1200.20
/GD2: IC703.14 (DOUT), J1200.21
/GD3: IC704.14 (DOUT), J1200.22
/GD4: IC705.14 (DOUT), J1200.23
/GD5: IC706.14 (DOUT), J1200.24
/GD6: IC707.14 (DOUT), J1200.25
/GD7: IC708.14 (DOUT), J1200.26
/XA0: IC701.5 (A0), IC702.5 (A0), IC703.5 (A0), IC704.5 (A0), IC705.5 (A0), IC706.5 (A0), IC707.5 (A0), IC708.5 (A0), J1200.1
/XA1: IC701.7 (A1), IC702.7 (A1), IC703.7 (A1), IC704.7 (A1), IC705.7 (A1), IC706.7 (A1), IC707.7 (A1), IC708.7 (A1), J1200.2
/XA2: IC701.6 (A2), IC702.6 (A2), IC703.6 (A2), IC704.6 (A2), IC705.6 (A2), IC706.6 (A2), IC707.6 (A2), IC708.6 (A2), J1200.3
/XA3: IC701.12 (A3), IC702.12 (A3), IC703.12 (A3), IC704.12 (A3), IC705.12 (A3), IC706.12 (A3), IC707.12 (A3), IC708.12 (A3), J1200.4
/XA4: IC701.11 (A4), IC702.11 (A4), IC703.11 (A4), IC704.11 (A4), IC705.11 (A4), IC706.11 (A4), IC707.11 (A4), IC708.11 (A4), J1200.5
/XA5: IC701.10 (A5), IC702.10 (A5), IC703.10 (A5), IC704.10 (A5), IC705.10 (A5), IC706.10 (A5), IC707.10 (A5), IC708.10 (A5), J1200.6
/XA6: IC701.13 (A6), IC702.13 (A6), IC703.13 (A6), IC704.13 (A6), IC705.13 (A6), IC706.13 (A6), IC707.13 (A6), IC708.13 (A6), J1200.7
/XA7: IC701.9 (A7), IC702.9 (A7), IC703.9 (A7), IC704.9 (A7), IC705.9 (A7), IC706.9 (A7), IC707.9 (A7), IC708.9 (A7), J1200.8
CAS0: J1200.29
CAS1: IC701.15 (~CAS), IC702.15 (~CAS), IC703.15 (~CAS), IC704.15 (~CAS), IC705.15 (~CAS), IC706.15 (~CAS), IC707.15 (~CAS), IC708.15 (~CAS), J1200.28
GND: C700.2, C701.2, C702.2, C703.2, C704.2, C705.2, C706.2, C707.2, C708.2, H8.1, IC701.16 (GND), IC702.16 (GND), IC703.16 (GND), IC704.16 (GND), IC705.16 (GND), IC706.16 (GND), IC707.16 (GND), IC708.16 (GND), J1200.17, J1200.18, R1220.1
MV: IC701.1 (NC), IC702.1 (NC), IC703.1 (NC), IC704.1 (NC), IC705.1 (NC), IC706.1 (NC), IC707.1 (NC), IC708.1 (NC)
MWE: IC701.3 (~WRITE), IC702.3 (~WRITE), IC703.3 (~WRITE), IC704.3 (~WRITE), IC705.3 (~WRITE), IC706.3 (~WRITE), IC707.3 (~WRITE), IC708.3 (~WRITE), J1200.31
unnamed: D1220.1 (K), R1220.2
RAS: IC701.4 (~RAS), IC702.4 (~RAS), IC703.4 (~RAS), IC704.4 (~RAS), IC705.4 (~RAS), IC706.4 (~RAS), IC707.4 (~RAS), IC708.4 (~RAS), J1200.30
RSV1: J1200.33
RSV2: J1200.32

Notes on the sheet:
RAM UPPER 64K

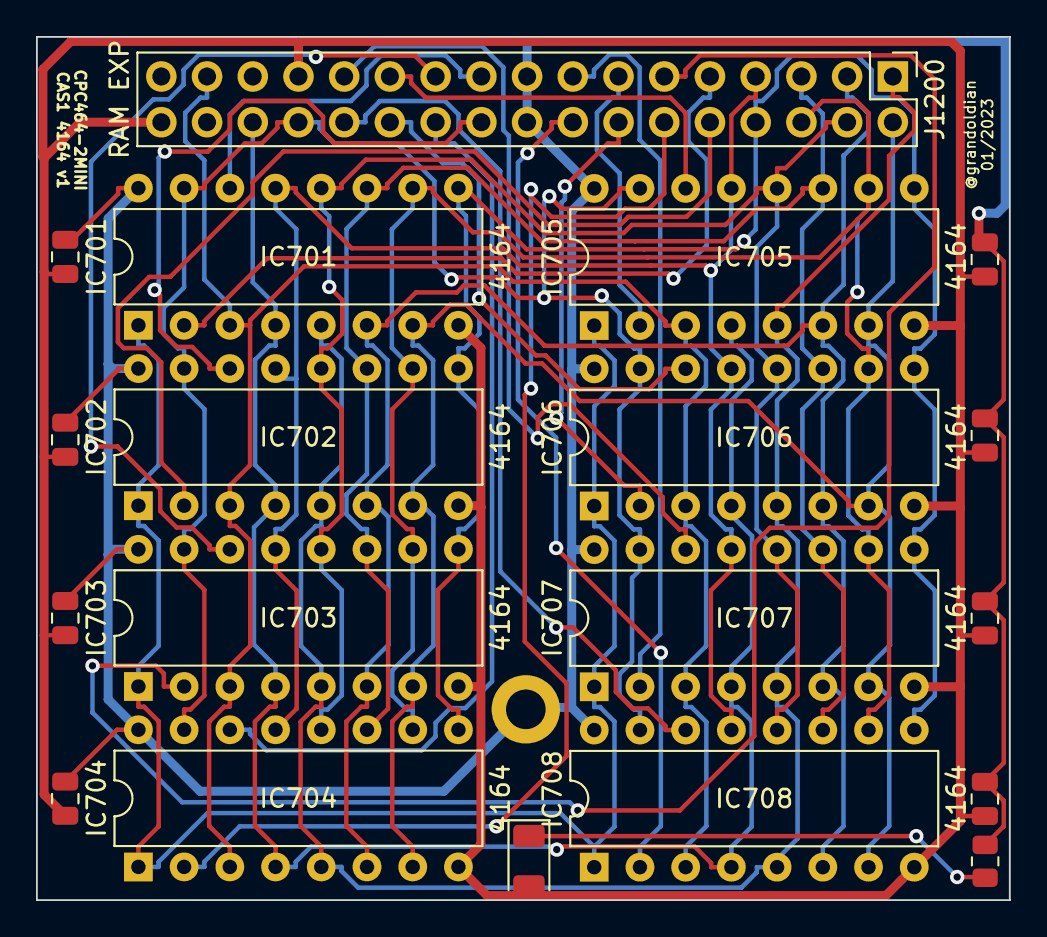
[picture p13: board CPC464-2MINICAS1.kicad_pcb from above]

Board: 2 copper layers, 54.1 x 48.0 mm, 20 parts (0 on the bottom side), 31 nets.

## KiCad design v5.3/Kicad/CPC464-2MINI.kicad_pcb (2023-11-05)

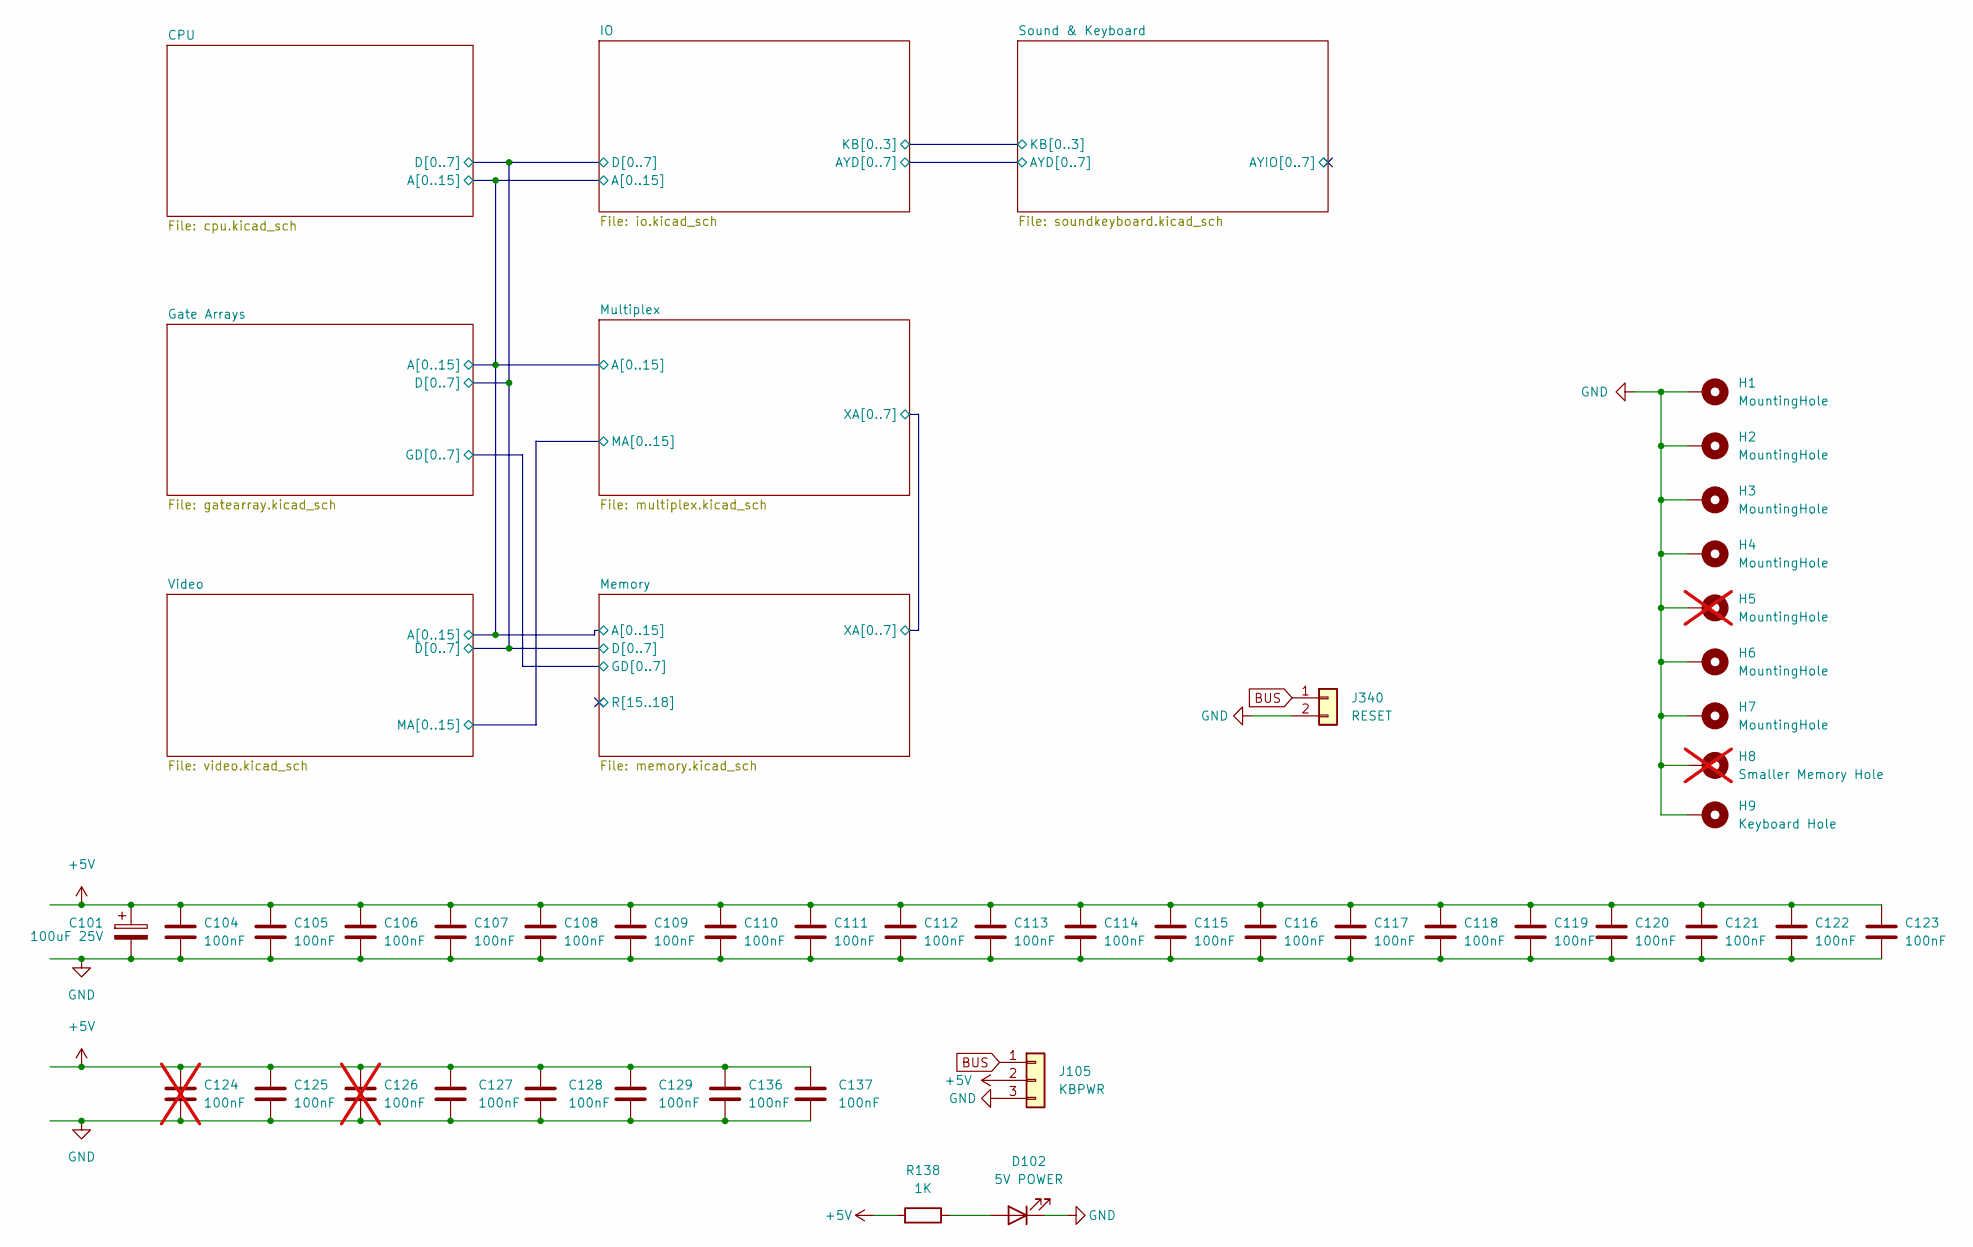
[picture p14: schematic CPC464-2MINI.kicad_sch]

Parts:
C101: 100uF 25V; CP_Radial_D5.0mm_P2.50mm
C104, C105, C106, C107, C108, C109, C110, C111, C112, C113, C114, C115, C116, C117, C118, C119, C120, C121, C122, C123, C125, C127, C128, C129, C136, C137: 100nF; C_0805_2012Metric; LCSC C49678
C124, C126: 100nF; C_0805_2012Metric; LCSC C49678; not fitted
D102: 5V POWER; LED_1206_3216Metric
H1, H2, H3, H4, H6, H7: MountingHole; MountingHole_2.7mm_M2.5_ISO14580_Pad
H5: MountingHole; MountingHole_2.7mm_M2.5_ISO14580_Pad; not fitted
H8: Smaller Memory Hole; MountingHole_2.2mm_M2_DIN965_Pad; not fitted
H9: Keyboard Hole; MountingHole_2.7mm_M2.5_ISO14580_Pad
J105: KBPWR; PinHeader_1x03_P2.54mm_Vertical
J340: RESET; PinHeader_1x02_P2.54mm_Vertical
R138: 1K; R_0805_2012Metric

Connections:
+5V: C101.1, C104.1, C105.1, C106.1, C107.1, C108.1, C109.1, C110.1, C111.1, C112.1, C113.1, C114.1, C115.1, C116.1, C117.1, C118.1, C119.1, C120.1, C121.1, C122.1, C123.1, C124.1, C125.1, C126.1, C127.1, C128.1, C129.1, C136.1, C137.1, J105.2, R138.2; also elsewhere on the board
BUS: J105.1, J340.1; also elsewhere on the board
GND: C101.2, C104.2, C105.2, C106.2, C107.2, C108.2, C109.2, C110.2, C111.2, C112.2, C113.2, C114.2, C115.2, C116.2, C117.2, C118.2, C119.2, C120.2, C121.2, C122.2, C123.2, C124.2, C125.2, C126.2, C127.2, C128.2, C129.2, C136.2, C137.2, D102.1 (K), H1.1, H2.1, H3.1, H4.1, H5.1, H6.1, H7.1, H8.1, H9.1, J105.3, J340.2; also elsewhere on the board
unnamed: D102.2 (A), R138.1

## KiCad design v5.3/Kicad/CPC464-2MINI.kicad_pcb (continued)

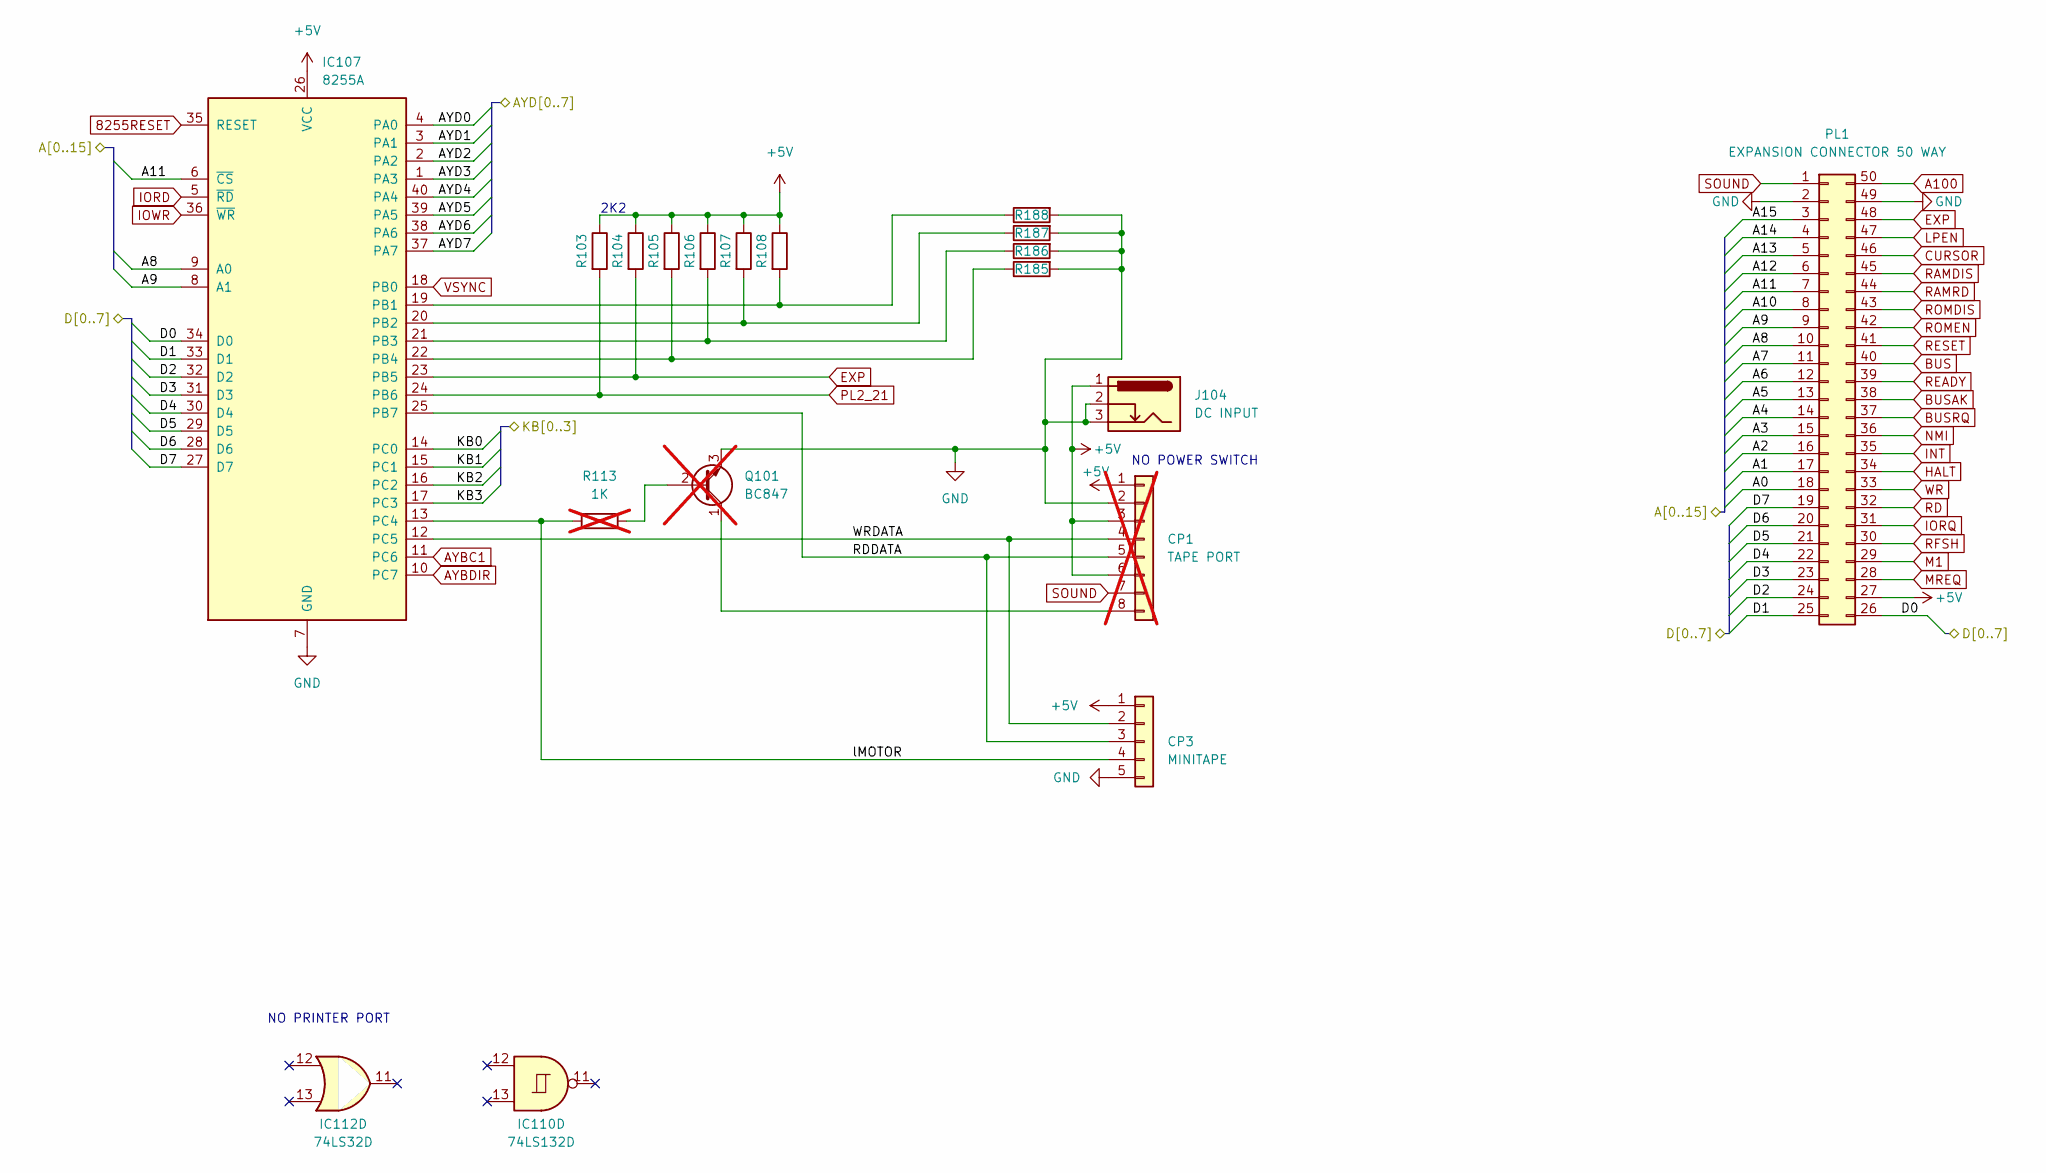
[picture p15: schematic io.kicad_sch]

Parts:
CP1: TAPE PORT; PinHeader_1x08_P2.54mm_Vertical; not fitted
CP3: MINITAPE; PinHeader_1x05_P2.54mm_Vertical
IC107: 8255A; DIP-40_W15.24mm
IC110: 74LS132D; SOIC-14_3.9x8.7mm_P1.27mm
IC112: 74LS32D; SOIC-14_3.9x8.7mm_P1.27mm
J104: DC INPUT; BarrelJack_Horizontal
PL1: EXPANSION CONNECTOR 50 WAY; EXPANSION_IDC_ANONYMISED
Q101: BC847; TO-92_Inline; not fitted
R103, R104, R105, R106, R107, R108: 2K2; R_0805_2012Metric; LCSC C114561
R113: 1K; R_0805_2012Metric; LCSC C482939; not fitted
R185, R186, R187, R188: 0R; R_0805_2012Metric; LCSC C114561

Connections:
8255RESET: IC107.35 (RESET); also elsewhere on the board
+5V: CP1.1, CP1.3, CP1.6, CP3.1, IC107.26 (VCC), J104.1, PL1.27, R103.1, R104.1, R105.1, R106.1, R107.1, R108.1; also elsewhere on the board
/CPU/A0: PL1.18; also elsewhere on the board
/CPU/A1: PL1.17; also elsewhere on the board
/CPU/A2: PL1.16; also elsewhere on the board
/CPU/A3: PL1.15; also elsewhere on the board
/CPU/A4: PL1.14; also elsewhere on the board
/CPU/A5: PL1.13; also elsewhere on the board
/CPU/A6: PL1.12; also elsewhere on the board
/CPU/A7: PL1.11; also elsewhere on the board
/CPU/A8: IC107.9 (A0), PL1.10; also elsewhere on the board
/CPU/A9: IC107.8 (A1), PL1.9; also elsewhere on the board
/CPU/A10: PL1.8; also elsewhere on the board
/CPU/A11: IC107.6 (~CS), PL1.7; also elsewhere on the board
/CPU/A12: PL1.6; also elsewhere on the board
/CPU/A13: PL1.5; also elsewhere on the board
/CPU/A14: PL1.4; also elsewhere on the board
/CPU/A15: PL1.3; also elsewhere on the board
/CPU/D0: IC107.34 (D0), PL1.26; also elsewhere on the board
/CPU/D1: IC107.33 (D1), PL1.25; also elsewhere on the board
/CPU/D2: IC107.32 (D2), PL1.24; also elsewhere on the board
/CPU/D3: IC107.31 (D3), PL1.23; also elsewhere on the board
/CPU/D4: IC107.30 (D4), PL1.22; also elsewhere on the board
/CPU/D5: IC107.29 (D5), PL1.21; also elsewhere on the board
/CPU/D6: IC107.28 (D6), PL1.20; also elsewhere on the board
/CPU/D7: IC107.27 (D7), PL1.19; also elsewhere on the board
/IO/AYD0: IC107.4 (PA0); also elsewhere on the board
/IO/AYD1: IC107.3 (PA1); also elsewhere on the board
/IO/AYD2: IC107.2 (PA2); also elsewhere on the board
/IO/AYD3: IC107.1 (PA3); also elsewhere on the board
/IO/AYD4: IC107.40 (PA4); also elsewhere on the board
/IO/AYD5: IC107.39 (PA5); also elsewhere on the board
/IO/AYD6: IC107.38 (PA6); also elsewhere on the board
/IO/AYD7: IC107.37 (PA7); also elsewhere on the board
/IO/KB0: IC107.14 (PC0); also elsewhere on the board
/IO/KB1: IC107.15 (PC1); also elsewhere on the board
/IO/KB2: IC107.16 (PC2); also elsewhere on the board
/IO/KB3: IC107.17 (PC3); also elsewhere on the board
/IO/RDDATA: CP1.5, CP3.3, IC107.25 (PB7)
/IO/WRDATA: CP1.4, CP3.2, IC107.12 (PC5)
/IO/lMOTOR: CP3.4, IC107.13 (PC4), R113.1
A100: PL1.50; also elsewhere on the board
AYBC1: IC107.11 (PC6); also elsewhere on the board
AYBDIR: IC107.10 (PC7); also elsewhere on the board
BUS: PL1.40; also elsewhere on the board
BUSAK: PL1.38; also elsewhere on the board
BUSRQ: PL1.37; also elsewhere on the board
CURSOR: PL1.46; also elsewhere on the board
EXP: IC107.23 (PB5), PL1.48, R104.2
GND: CP1.2, CP3.5, IC107.7 (GND), J104.2, J104.3, PL1.2, PL1.49, Q101.3 (E), R185.2, R186.2, R187.2, R188.2; also elsewhere on the board
HALT: PL1.34; also elsewhere on the board
INT: PL1.35; also elsewhere on the board
IORD: IC107.5 (~RD); also elsewhere on the board
IORQ: PL1.31; also elsewhere on the board
IOWR: IC107.36 (~WR); also elsewhere on the board
LPEN: PL1.47; also elsewhere on the board
M1: PL1.29; also elsewhere on the board
MREQ: PL1.28; also elsewhere on the board
NMI: PL1.36; also elsewhere on the board
unnamed: CP1.8, Q101.1 (C)
unnamed: IC107.19 (PB1), R108.2, R188.1
unnamed: IC107.20 (PB2), R107.2, R187.1
unnamed: IC107.21 (PB3), R106.2, R186.1
unnamed: IC107.22 (PB4), R105.2, R185.1
unnamed: Q101.2 (B), R113.2
PL2_21: IC107.24 (PB6), R103.2
RAMDIS: PL1.45; also elsewhere on the board
RAMRD: PL1.44; also elsewhere on the board
RD: PL1.32; also elsewhere on the board
READY: PL1.39; also elsewhere on the board
RESET: PL1.41; also elsewhere on the board
RFSH: PL1.30; also elsewhere on the board
ROMDIS: PL1.43; also elsewhere on the board
ROMEN: PL1.42; also elsewhere on the board
SOUND: CP1.7, PL1.1; also elsewhere on the board
VSYNC: IC107.18 (PB0); also elsewhere on the board
WR: PL1.33; also elsewhere on the board

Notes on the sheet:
2K2
NO POWER SWITCH
NO PRINTER PORT

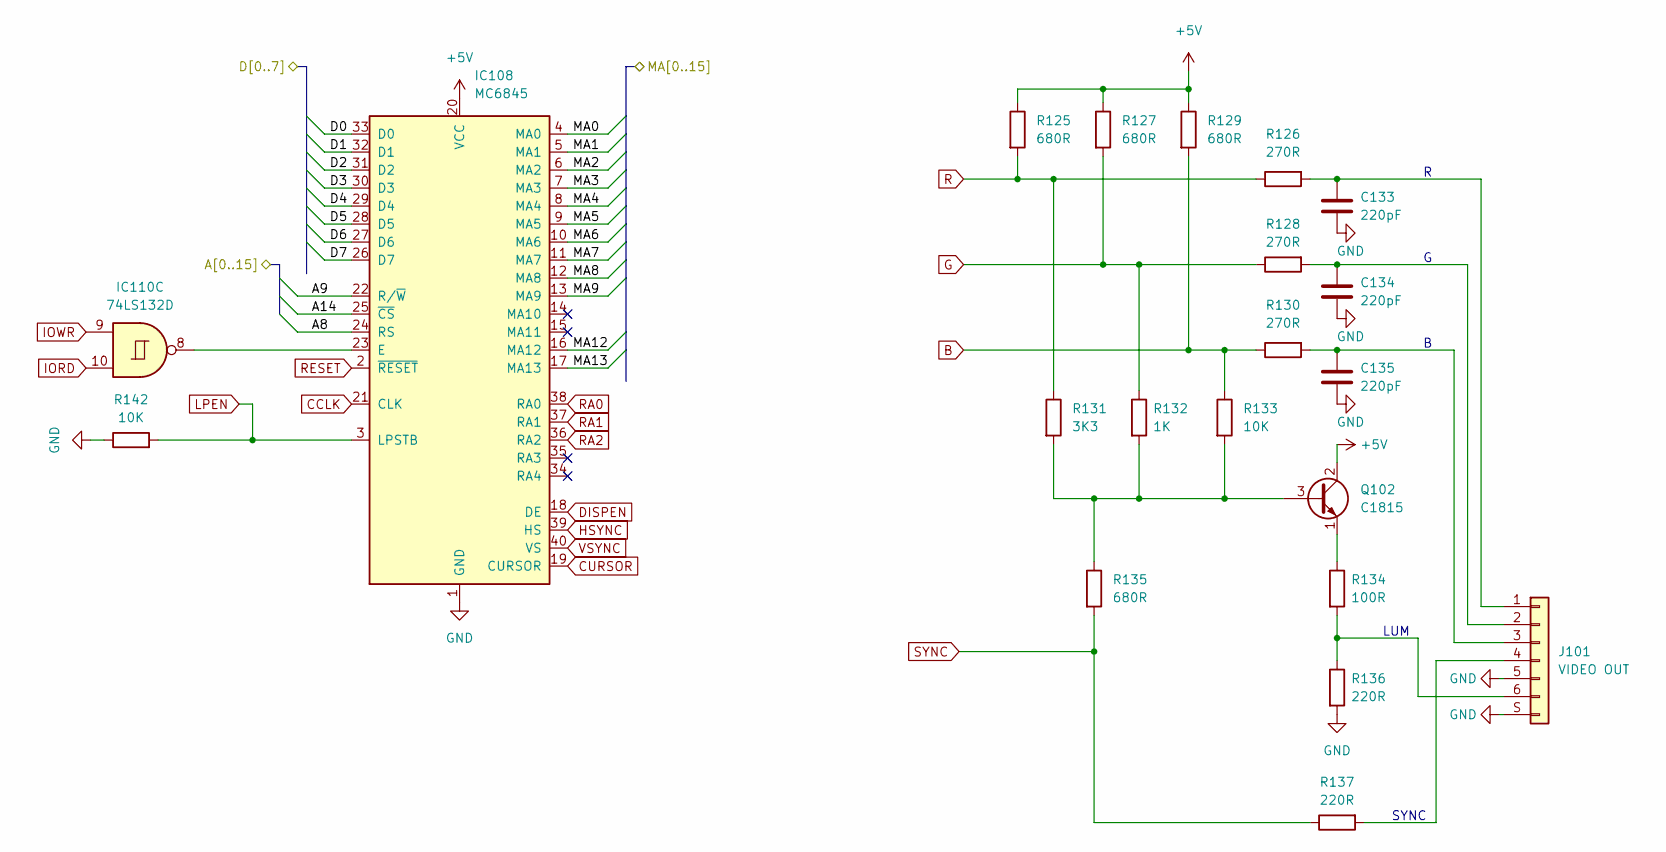
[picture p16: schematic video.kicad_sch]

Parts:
C133, C134, C135: 220pF; C_0805_2012Metric; LCSC C1727
IC108: MC6845; DIP-40_W15.24mm
IC110: 74LS132D; SOIC-14_3.9x8.7mm_P1.27mm
J101: VIDEO OUT; VIDEOJACK
Q102: C1815; SOT-23
R125, R127, R129, R135: 680R; R_0805_2012Metric; LCSC C114549
R126, R128, R130: 270R; R_0805_2012Metric; LCSC C137558
R131: 3K3; R_0805_2012Metric; LCSC C114531
R132: 1K; R_0805_2012Metric; LCSC C482939
R133, R142: 10K; R_0805_2012Metric; LCSC C84376
R134: 100R; R_0805_2012Metric; LCSC C105577
R136, R137: 220R; R_0805_2012Metric; LCSC C114519

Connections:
+5V: IC108.20 (VCC), Q102.2 (C), R125.1, R127.1, R129.1; also elsewhere on the board
/CPU/A8: IC108.24 (RS); also elsewhere on the board
/CPU/A9: IC108.22 (R/~W); also elsewhere on the board
/CPU/A14: IC108.25 (~CS); also elsewhere on the board
/CPU/D0: IC108.33 (D0); also elsewhere on the board
/CPU/D1: IC108.32 (D1); also elsewhere on the board
/CPU/D2: IC108.31 (D2); also elsewhere on the board
/CPU/D3: IC108.30 (D3); also elsewhere on the board
/CPU/D4: IC108.29 (D4); also elsewhere on the board
/CPU/D5: IC108.28 (D5); also elsewhere on the board
/CPU/D6: IC108.27 (D6); also elsewhere on the board
/CPU/D7: IC108.26 (D7); also elsewhere on the board
/Multiplex/MA0: IC108.4 (MA0); also elsewhere on the board
/Multiplex/MA1: IC108.5 (MA1); also elsewhere on the board
/Multiplex/MA2: IC108.6 (MA2); also elsewhere on the board
/Multiplex/MA3: IC108.7 (MA3); also elsewhere on the board
/Multiplex/MA4: IC108.8 (MA4); also elsewhere on the board
/Multiplex/MA5: IC108.9 (MA5); also elsewhere on the board
/Multiplex/MA6: IC108.10 (MA6); also elsewhere on the board
/Multiplex/MA7: IC108.11 (MA7); also elsewhere on the board
/Multiplex/MA8: IC108.12 (MA8); also elsewhere on the board
/Multiplex/MA9: IC108.13 (MA9); also elsewhere on the board
/Multiplex/MA12: IC108.16 (MA12); also elsewhere on the board
/Multiplex/MA13: IC108.17 (MA13); also elsewhere on the board
B: R129.2, R130.1, R133.1; also elsewhere on the board
CCLK: IC108.21 (CLK); also elsewhere on the board
CURSOR: IC108.19 (CURSOR); also elsewhere on the board
DISPEN: IC108.18 (DE); also elsewhere on the board
G: R127.2, R128.1, R132.1; also elsewhere on the board
GND: C133.2, C134.2, C135.2, IC108.1 (GND), J101.5, J101.S (Shield), R136.2, R142.1; also elsewhere on the board
HSYNC: IC108.39 (HS); also elsewhere on the board
IORD: IC110.10; also elsewhere on the board
IOWR: IC110.9; also elsewhere on the board
LPEN: IC108.3 (LPSTB), R142.2; also elsewhere on the board
unnamed: IC108.23 (E), IC110.8
unnamed: C133.1, J101.1, R126.2
unnamed: C134.1, J101.2, R128.2
unnamed: C135.1, J101.3, R130.2
unnamed: J101.4, R137.2
unnamed: J101.6, R134.2, R136.1
unnamed: Q102.3 (B), R131.2, R132.2, R133.2, R135.1
unnamed: Q102.1 (E), R134.1
R: R125.2, R126.1, R131.1; also elsewhere on the board
RA0: IC108.38 (RA0); also elsewhere on the board
RA1: IC108.37 (RA1); also elsewhere on the board
RA2: IC108.36 (RA2); also elsewhere on the board
RESET: IC108.2 (~RESET); also elsewhere on the board
SYNC: R135.2, R137.1; also elsewhere on the board
VSYNC: IC108.40 (VS); also elsewhere on the board

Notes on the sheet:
LUM
SYNC

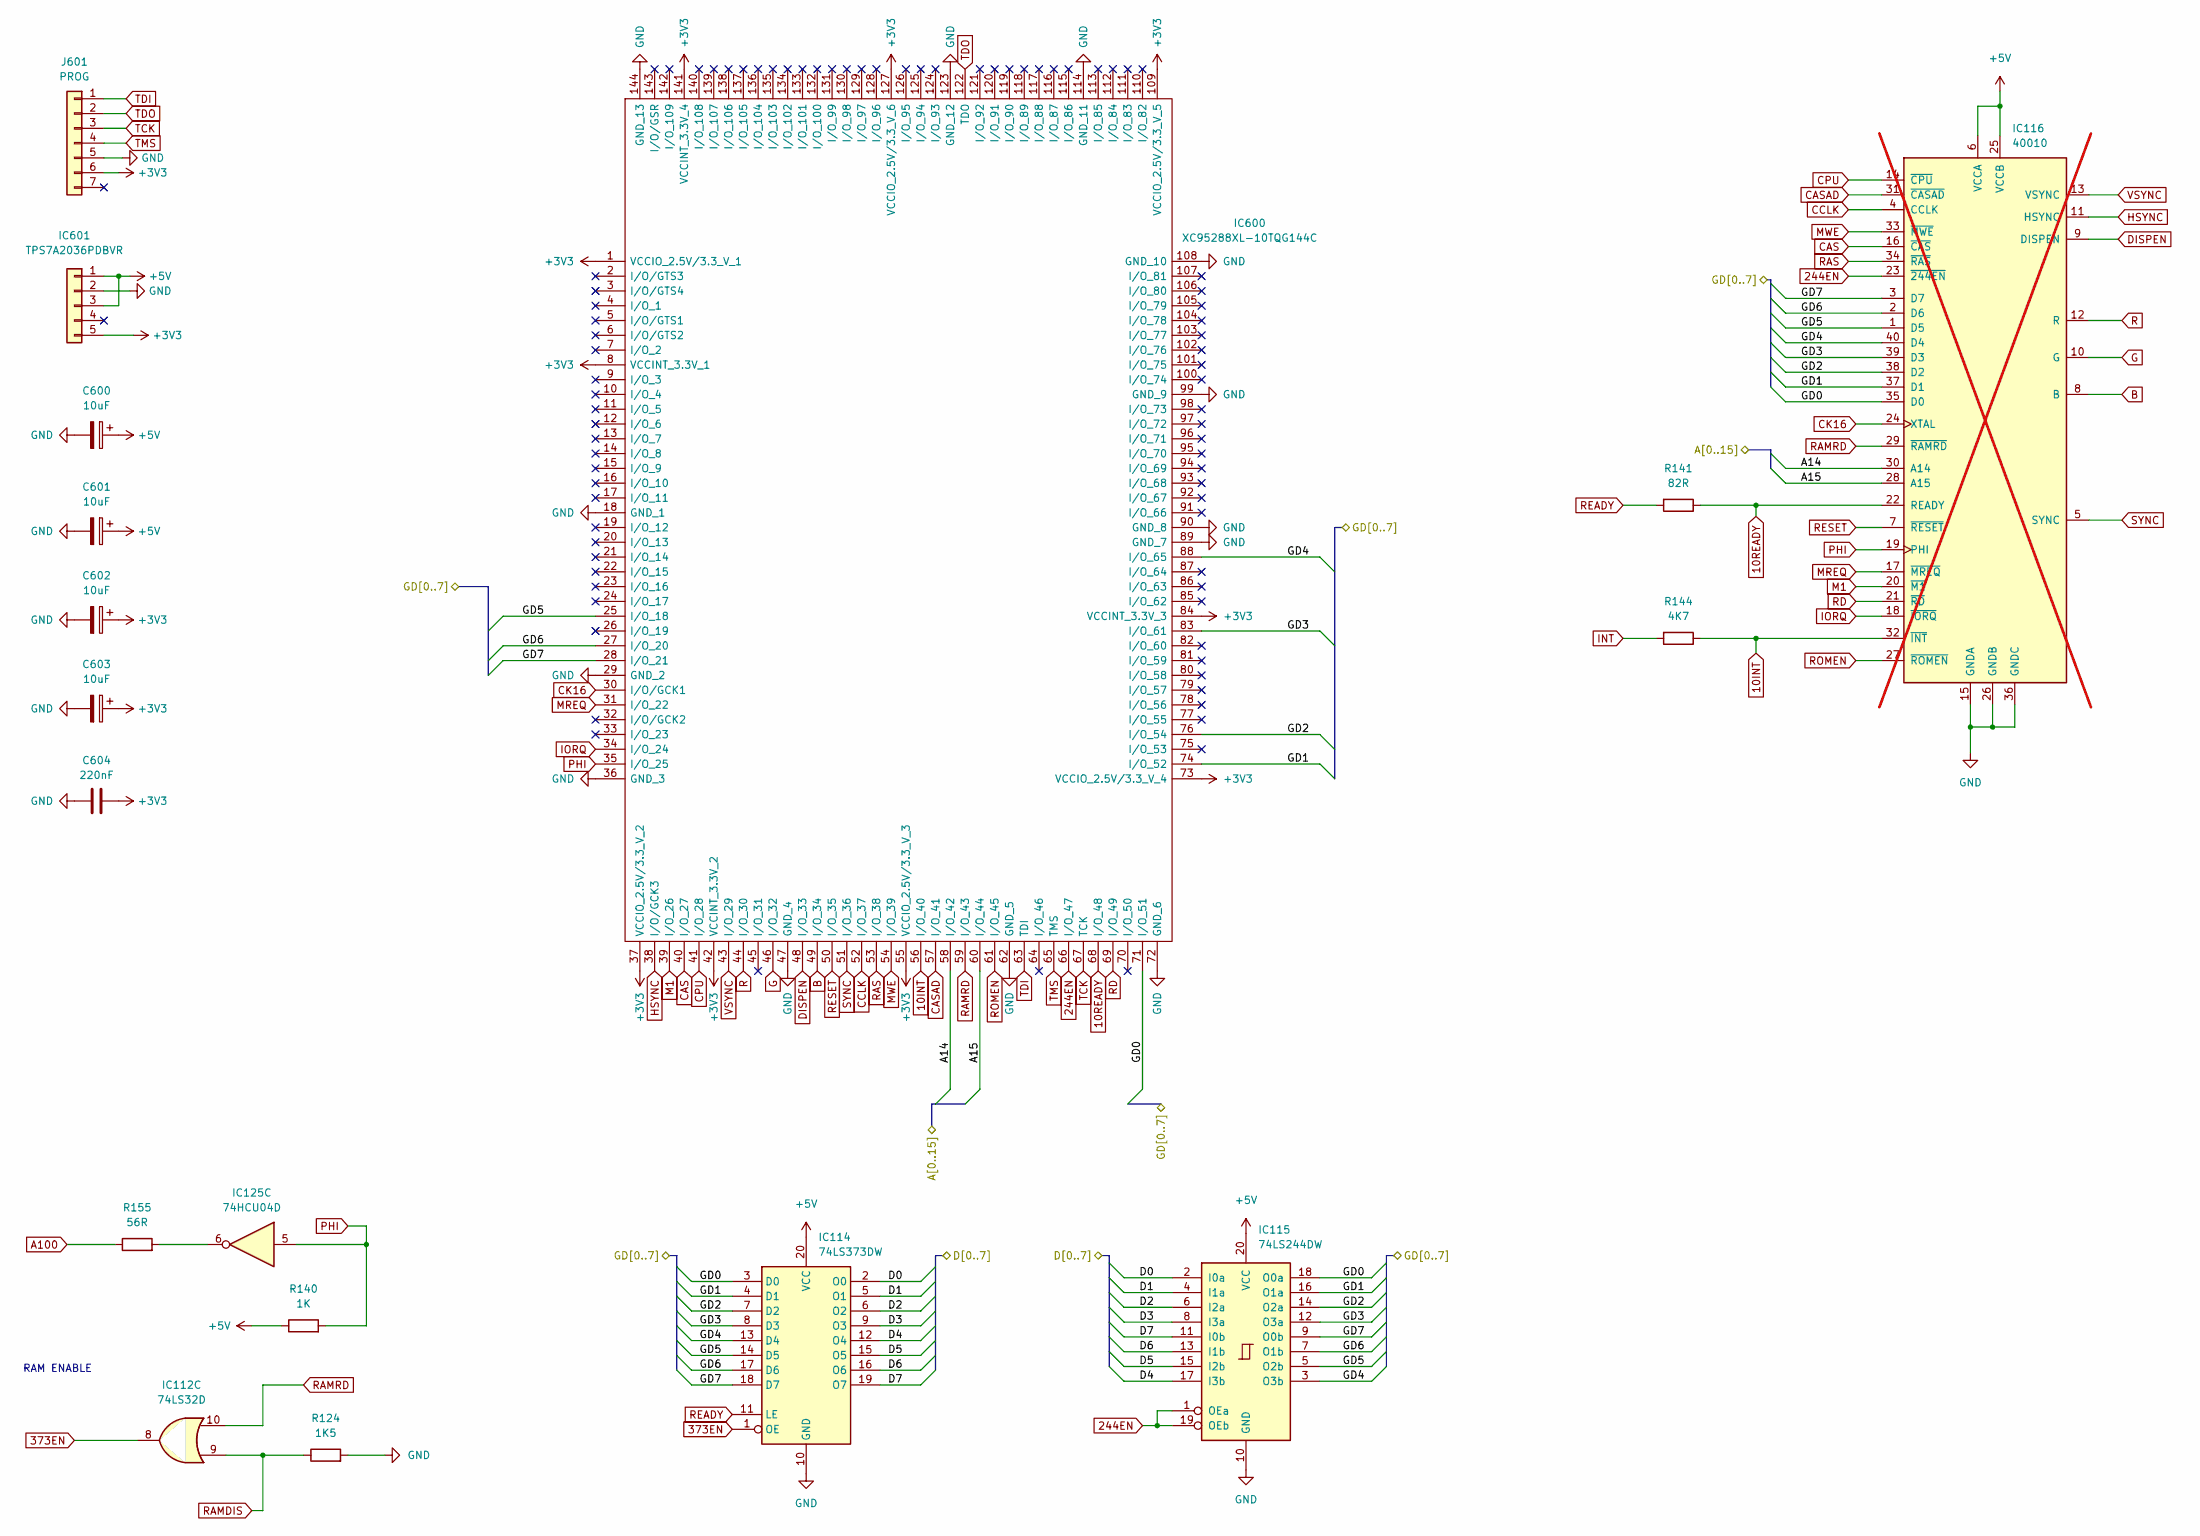
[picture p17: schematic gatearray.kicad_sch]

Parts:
C600, C601, C602, C603: 10uF; CP_EIA-3216-18_Kemet-A
C604: 220nF; R_0805_2012Metric
IC112: 74LS32D; SOIC-14_3.9x8.7mm_P1.27mm
IC114: 74LS373DW; SOIC-20W_7.5x12.8mm_P1.27mm
IC115: 74LS244DW; SOIC-20W_7.5x12.8mm_P1.27mm
IC116: 40010; DIP-40_W15.24mm; not fitted
IC125: 74HCU04D; SOIC-14_3.9x8.7mm_P1.27mm
IC600: XC95288XL-10TQG144C; QFP50P2200X2200X160-144N; Mouser Part Number 217-5288XL-10TQG144C
IC601: TPS7A2036PDBVR; SOT-23-5
J601: PROG; PinHeader_1x07_P2.54mm_Vertical
R124: 1K5; R_0805_2012Metric; LCSC C114555
R140: 1K; R_0805_2012Metric; LCSC C482939
R141: 82R; R_0805_2012Metric; LCSC C706251
R144: 4K7; R_0805_2012Metric; LCSC C60816
R155: 56R; R_0805_2012Metric; LCSC C144135

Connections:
10INT: IC116.32 (~INT), IC600.56 (I/O_40), R144.1
10READY: IC116.22 (READY), IC600.68 (I/O_48), R141.1
244EN: IC115.1 (OEa), IC115.19 (OEb), IC116.23 (~244EN), IC600.66 (I/O_47)
373EN: IC112.8, IC114.1 (OE)
+3V3: C602.1, C603.1, C604.2, IC600.1 (VCCIO_2.5V/3.3_V_1), IC600.8 (VCCINT_3.3V_1), IC600.37 (VCCIO_2.5V/3.3_V_2), IC600.42 (VCCINT_3.3V_2), IC600.55 (VCCIO_2.5V/3.3_V_3), IC600.73 (VCCIO_2.5V/3.3_V_4), IC600.84 (VCCINT_3.3V_3), IC600.109 (VCCIO_2.5V/3.3_V_5), IC600.127 (VCCIO_2.5V/3.3_V_6), IC600.141 (VCCINT_3.3V_4), IC601.5, J601.6
+5V: C600.1, C601.1, IC114.20 (VCC), IC115.20 (VCC), IC116.6 (VCCA), IC116.25 (VCCB), IC601.1, IC601.3, R140.1; also elsewhere on the board
/CPU/A14: IC116.30 (A14), IC600.58 (I/O_42); also elsewhere on the board
/CPU/A15: IC116.28 (A15), IC600.60 (I/O_44); also elsewhere on the board
/CPU/D0: IC114.2 (O0), IC115.2 (I0a); also elsewhere on the board
/CPU/D1: IC114.5 (O1), IC115.4 (I1a); also elsewhere on the board
/CPU/D2: IC114.6 (O2), IC115.6 (I2a); also elsewhere on the board
/CPU/D3: IC114.9 (O3), IC115.8 (I3a); also elsewhere on the board
/CPU/D4: IC114.12 (O4), IC115.17 (I3b); also elsewhere on the board
/CPU/D5: IC114.15 (O5), IC115.15 (I2b); also elsewhere on the board
/CPU/D6: IC114.16 (O6), IC115.13 (I1b); also elsewhere on the board
/CPU/D7: IC114.19 (O7), IC115.11 (I0b); also elsewhere on the board
/Gate Arrays/GD0: IC114.3 (D0), IC115.18 (O0a), IC116.35 (D0), IC600.71 (I/O_51); also elsewhere on the board
/Gate Arrays/GD1: IC114.4 (D1), IC115.16 (O1a), IC116.37 (D1), IC600.74 (I/O_52); also elsewhere on the board
/Gate Arrays/GD2: IC114.7 (D2), IC115.14 (O2a), IC116.38 (D2), IC600.76 (I/O_54); also elsewhere on the board
/Gate Arrays/GD3: IC114.8 (D3), IC115.12 (O3a), IC116.39 (D3), IC600.83 (I/O_61); also elsewhere on the board
/Gate Arrays/GD4: IC114.13 (D4), IC115.3 (O3b), IC116.40 (D4), IC600.88 (I/O_65); also elsewhere on the board
/Gate Arrays/GD5: IC114.14 (D5), IC115.5 (O2b), IC116.1 (D5), IC600.25 (I/O_18); also elsewhere on the board
/Gate Arrays/GD6: IC114.17 (D6), IC115.7 (O1b), IC116.2 (D6), IC600.27 (I/O_20); also elsewhere on the board
/Gate Arrays/GD7: IC114.18 (D7), IC115.9 (O0b), IC116.3 (D7), IC600.28 (I/O_21); also elsewhere on the board
A100: R155.1; also elsewhere on the board
B: IC116.8 (B), IC600.49 (I/O_34); also elsewhere on the board
CAS: IC116.16 (~CAS), IC600.40 (I/O_27); also elsewhere on the board
CASAD: IC116.31 (~CASAD), IC600.57 (I/O_41); also elsewhere on the board
CCLK: IC116.4 (CCLK), IC600.52 (I/O_37); also elsewhere on the board
CK16: IC116.24 (XTAL), IC600.30 (I/O/GCK1); also elsewhere on the board
CPU: IC116.14 (~CPU), IC600.41 (I/O_28); also elsewhere on the board
DISPEN: IC116.9 (DISPEN), IC600.48 (I/O_33); also elsewhere on the board
G: IC116.10 (G), IC600.46 (I/O_32); also elsewhere on the board
GND: C600.2, C601.2, C602.2, C603.2, C604.1, IC114.10 (GND), IC115.10 (GND), IC116.15 (GNDA), IC116.26 (GNDB), IC116.36 (GNDC), IC600.18 (GND_1), IC600.29 (GND_2), IC600.36 (GND_3), IC600.47 (GND_4), IC600.62 (GND_5), IC600.72 (GND_6), IC600.89 (GND_7), IC600.90 (GND_8), IC600.99 (GND_9), IC600.108 (GND_10), IC600.114 (GND_11), IC600.123 (GND_12), IC600.144 (GND_13), IC601.2, J601.5, R124.2; also elsewhere on the board
HSYNC: IC116.11 (HSYNC), IC600.38 (I/O/GCK3); also elsewhere on the board
INT: R144.2; also elsewhere on the board
IORQ: IC116.18 (~IORQ), IC600.34 (I/O_24); also elsewhere on the board
M1: IC116.20 (~M1), IC600.39 (I/O_26); also elsewhere on the board
MREQ: IC116.17 (~MREQ), IC600.31 (I/O_22); also elsewhere on the board
MWE: IC116.33 (~MWE), IC600.54 (I/O_39); also elsewhere on the board
unnamed: IC125.6, R155.2
PHI: IC116.19 (PHI), IC125.5, IC600.35 (I/O_25), R140.2
R: IC116.12 (R), IC600.44 (I/O_30); also elsewhere on the board
RAMDIS: IC112.9, R124.1; also elsewhere on the board
RAMRD: IC112.10, IC116.29 (~RAMRD), IC600.59 (I/O_43); also elsewhere on the board
RAS: IC116.34 (~RAS), IC600.53 (I/O_38); also elsewhere on the board
RD: IC116.21 (~RD), IC600.69 (I/O_49); also elsewhere on the board
READY: IC114.11 (LE), R141.2; also elsewhere on the board
RESET: IC116.7 (~RESET), IC600.50 (I/O_35); also elsewhere on the board
ROMEN: IC116.27 (~ROMEN), IC600.61 (I/O_45); also elsewhere on the board
SYNC: IC116.5 (SYNC), IC600.51 (I/O_36); also elsewhere on the board
TCK: IC600.67 (TCK), J601.3
TDI: IC600.63 (TDI), J601.1
TDO: IC600.122 (TDO), J601.2
TMS: IC600.65 (TMS), J601.4
VSYNC: IC116.13 (VSYNC), IC600.43 (I/O_29); also elsewhere on the board

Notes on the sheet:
RAM ENABLE

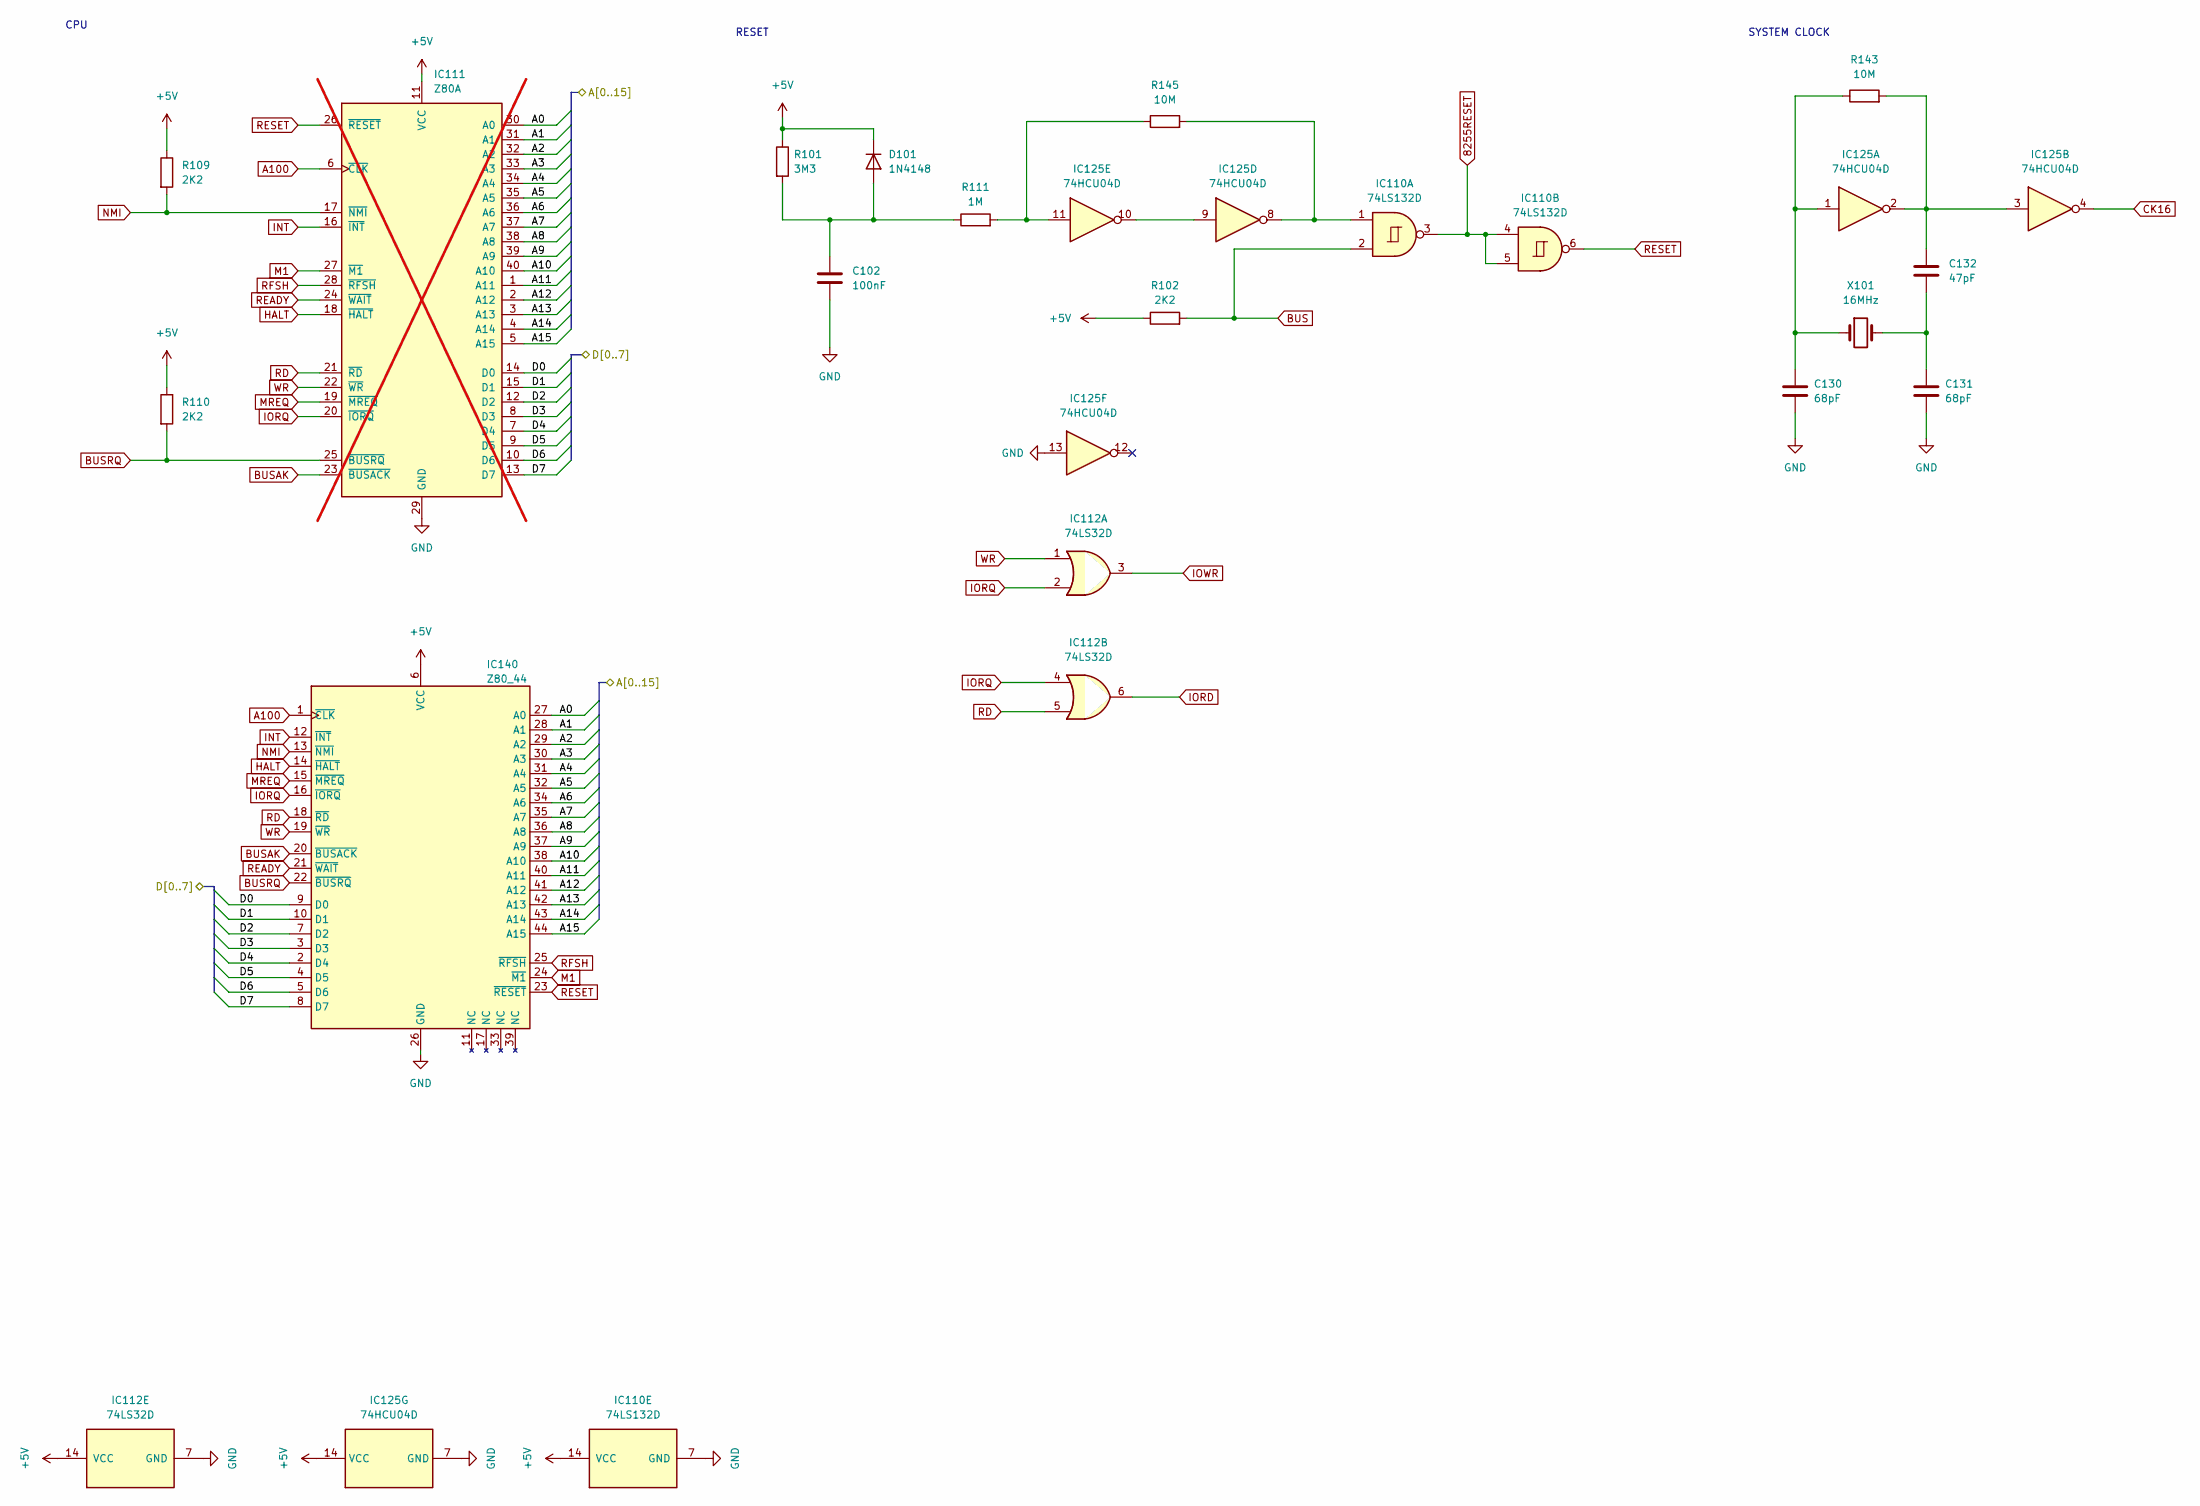
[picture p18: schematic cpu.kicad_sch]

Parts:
C102: 100nF; C_0805_2012Metric; LCSC C49678
C130, C131: 68pF; C_0805_2012Metric; LCSC C1834
C132: 47pF; C_0805_2012Metric; LCSC C24659
D101: 1N4148; D101; LCSC C2099
IC110: 74LS132D; SOIC-14_3.9x8.7mm_P1.27mm
IC111: Z80A; DIP-40_W15.24mm; not fitted
IC112: 74LS32D; SOIC-14_3.9x8.7mm_P1.27mm
IC125: 74HCU04D; SOIC-14_3.9x8.7mm_P1.27mm
IC140: Z80_44; LQFP-44_10x10mm_P0.8mm
R101: 3M3; R_0805_2012Metric; LCSC C483095
R102, R109, R110: 2K2; R_0805_2012Metric; LCSC C114561
R111: 1M; R_0805_2012Metric; LCSC C482940
R143, R145: 10M; R_0805_2012Metric; LCSC C309665
X101: 16MHz; Crystal_HC49-U_Vertical

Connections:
8255RESET: IC110.3, IC110.4, IC110.5; also elsewhere on the board
+5V: D101.1 (K), IC110.14 (VCC), IC111.11 (VCC), IC112.14 (VCC), IC125.14 (VCC), IC140.6 (VCC), R101.1, R102.1, R109.1, R110.1; also elsewhere on the board
/CPU/A0: IC111.30 (A0), IC140.27 (A0); also elsewhere on the board
/CPU/A1: IC111.31 (A1), IC140.28 (A1); also elsewhere on the board
/CPU/A2: IC111.32 (A2), IC140.29 (A2); also elsewhere on the board
/CPU/A3: IC111.33 (A3), IC140.30 (A3); also elsewhere on the board
/CPU/A4: IC111.34 (A4), IC140.31 (A4); also elsewhere on the board
/CPU/A5: IC111.35 (A5), IC140.32 (A5); also elsewhere on the board
/CPU/A6: IC111.36 (A6), IC140.34 (A6); also elsewhere on the board
/CPU/A7: IC111.37 (A7), IC140.35 (A7); also elsewhere on the board
/CPU/A8: IC111.38 (A8), IC140.36 (A8); also elsewhere on the board
/CPU/A9: IC111.39 (A9), IC140.37 (A9); also elsewhere on the board
/CPU/A10: IC111.40 (A10), IC140.38 (A10); also elsewhere on the board
/CPU/A11: IC111.1 (A11), IC140.40 (A11); also elsewhere on the board
/CPU/A12: IC111.2 (A12), IC140.41 (A12); also elsewhere on the board
/CPU/A13: IC111.3 (A13), IC140.42 (A13); also elsewhere on the board
/CPU/A14: IC111.4 (A14), IC140.43 (A14); also elsewhere on the board
/CPU/A15: IC111.5 (A15), IC140.44 (A15); also elsewhere on the board
/CPU/D0: IC111.14 (D0), IC140.9 (D0); also elsewhere on the board
/CPU/D1: IC111.15 (D1), IC140.10 (D1); also elsewhere on the board
/CPU/D2: IC111.12 (D2), IC140.7 (D2); also elsewhere on the board
/CPU/D3: IC111.8 (D3), IC140.3 (D3); also elsewhere on the board
/CPU/D4: IC111.7 (D4), IC140.2 (D4); also elsewhere on the board
/CPU/D5: IC111.9 (D5), IC140.4 (D5); also elsewhere on the board
/CPU/D6: IC111.10 (D6), IC140.5 (D6); also elsewhere on the board
/CPU/D7: IC111.13 (D7), IC140.8 (D7); also elsewhere on the board
A100: IC111.6 (~CLK), IC140.1 (~CLK); also elsewhere on the board
BUS: IC110.2, R102.2; also elsewhere on the board
BUSAK: IC111.23 (~BUSACK), IC140.20 (~BUSACK); also elsewhere on the board
BUSRQ: IC111.25 (~BUSRQ), IC140.22 (~BUSRQ), R110.2; also elsewhere on the board
CK16: IC125.4; also elsewhere on the board
GND: C102.2, C130.2, C131.2, IC110.7 (GND), IC111.29 (GND), IC112.7 (GND), IC125.7 (GND), IC125.13, IC140.26 (GND); also elsewhere on the board
HALT: IC111.18 (~HALT), IC140.14 (~HALT); also elsewhere on the board
INT: IC111.16 (~INT), IC140.12 (~INT); also elsewhere on the board
IORD: IC112.6; also elsewhere on the board
IORQ: IC111.20 (~IORQ), IC112.2, IC112.4, IC140.16 (~IORQ); also elsewhere on the board
IOWR: IC112.3; also elsewhere on the board
M1: IC111.27 (~M1), IC140.24 (~M1); also elsewhere on the board
MREQ: IC111.19 (~MREQ), IC140.15 (~MREQ); also elsewhere on the board
NMI: IC111.17 (~NMI), IC140.13 (~NMI), R109.2; also elsewhere on the board
unnamed: C130.1, IC125.1, R143.1, X101.1
unnamed: C131.1, C132.1, X101.2
unnamed: C132.2, IC125.2, IC125.3, R143.2
unnamed: C102.1, D101.2 (A), R101.2, R111.1
unnamed: IC110.1, IC125.8, R145.2
unnamed: IC125.9, IC125.10
unnamed: IC125.11, R111.2, R145.1
RD: IC111.21 (~RD), IC112.5, IC140.18 (~RD); also elsewhere on the board
READY: IC111.24 (~WAIT), IC140.21 (~WAIT); also elsewhere on the board
RESET: IC110.6, IC111.26 (~RESET), IC140.23 (~RESET); also elsewhere on the board
RFSH: IC111.28 (~RFSH), IC140.25 (~RFSH); also elsewhere on the board
WR: IC111.22 (~WR), IC112.1, IC140.19 (~WR); also elsewhere on the board

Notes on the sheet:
RESET
CPU
SYSTEM CLOCK

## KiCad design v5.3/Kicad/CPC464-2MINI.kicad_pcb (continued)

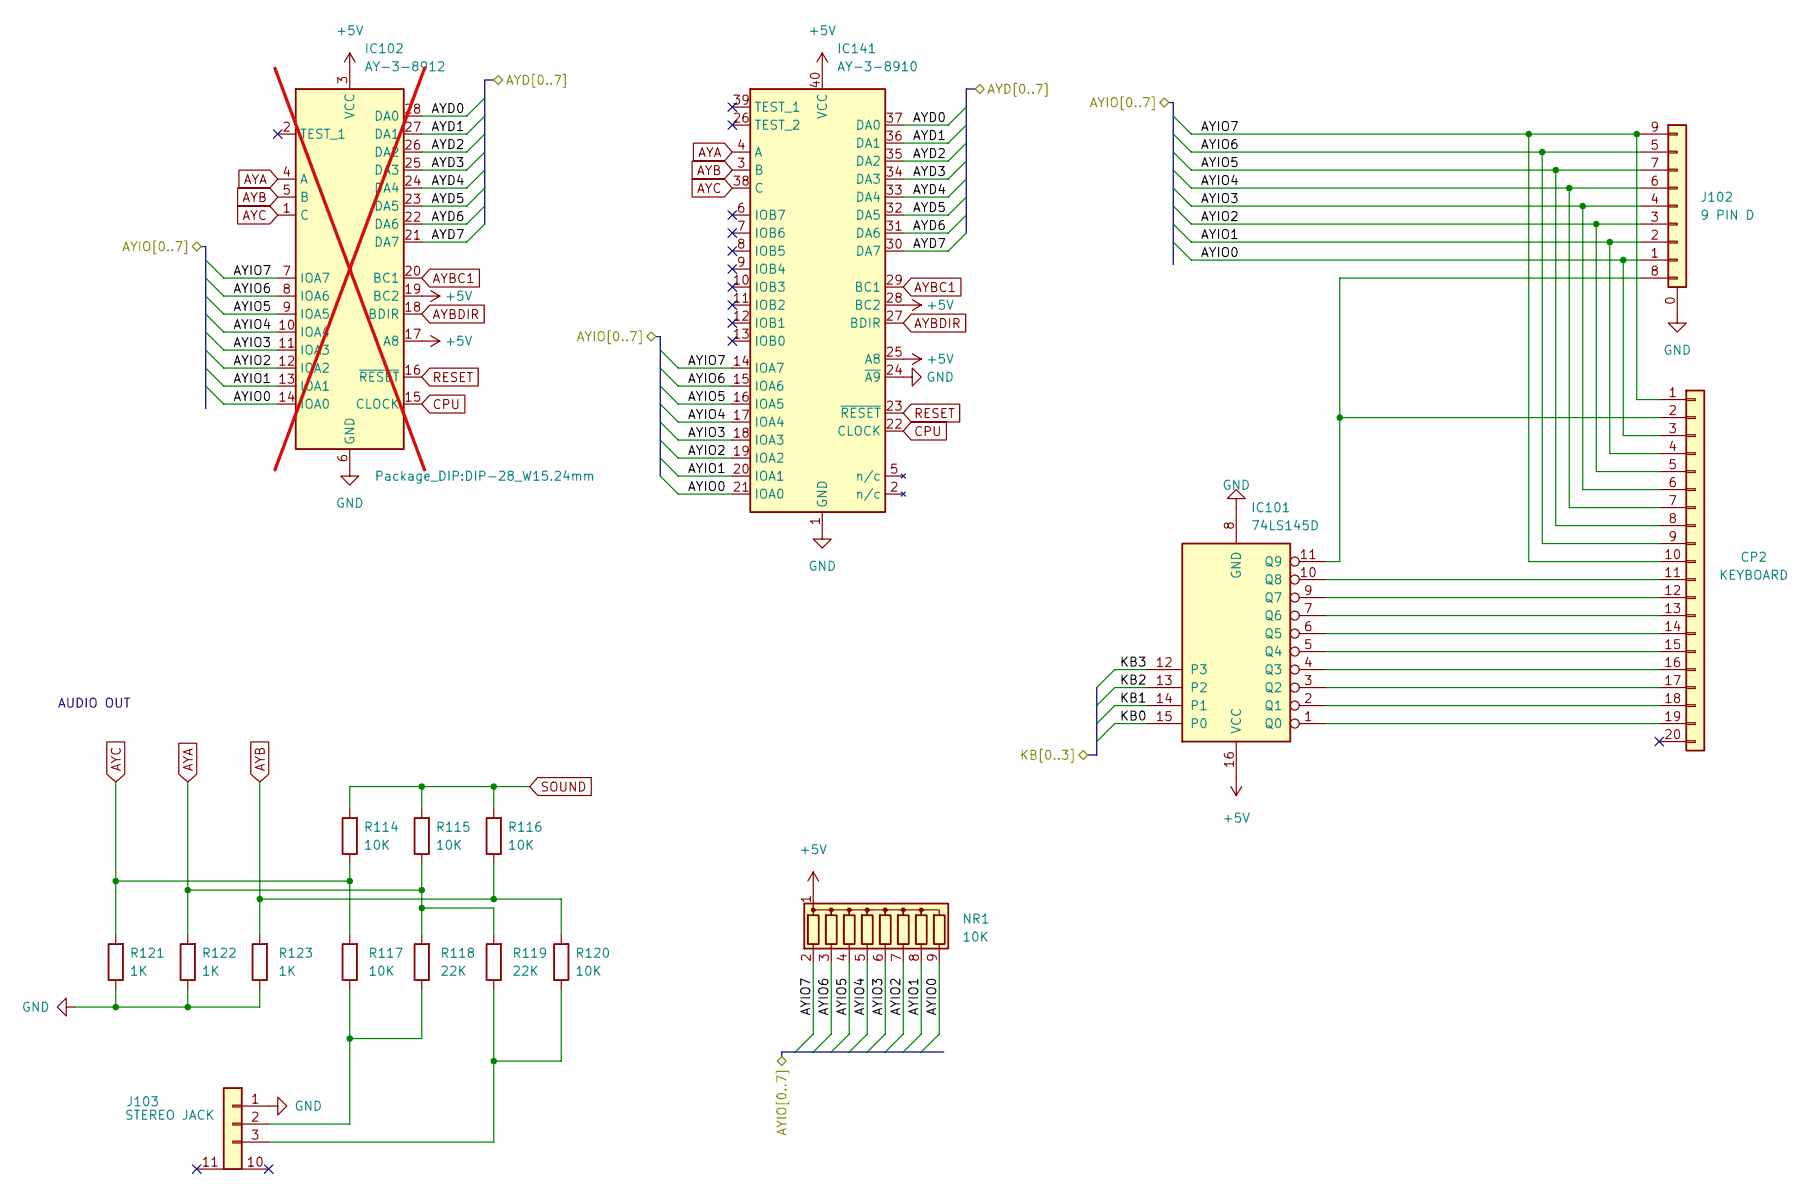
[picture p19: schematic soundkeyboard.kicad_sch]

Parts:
CP2: KEYBOARD; PinHeader_1x20_P2.54mm_Vertical
IC101: 74LS145D; SOIC-16_3.9x9.9mm_P1.27mm
IC102: AY-3-8912; DIP-28_W15.24mm; not fitted
IC141: AY-3-8910; DIP-40_W15.24mm
J102: 9 PIN D; DSUB-9_Male_Horizontal_P2.77x2.84mm_EdgePinOffset7.70mm_Hou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
J103: STEREO JACK; STEREO
NR1: 10K; R_Array_SIP9
R114, R115, R116, R117, R120: 10K; R_0805_2012Metric; LCSC C84376
R118, R119: 22K; R_0805_2012Metric; LCSC C114565
R121, R122, R123: 1K; R_0805_2012Metric; LCSC C482939

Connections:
+5V: IC101.16 (VCC), IC102.3 (VCC), IC102.17 (A8), IC102.19 (BC2), IC141.25 (A8), IC141.28 (BC2), IC141.40 (VCC), NR1.1 (common); also elsewhere on the board
/IO/AYD0: IC102.28 (DA0), IC141.37 (DA0); also elsewhere on the board
/IO/AYD1: IC102.27 (DA1), IC141.36 (DA1); also elsewhere on the board
/IO/AYD2: IC102.26 (DA2), IC141.35 (DA2); also elsewhere on the board
/IO/AYD3: IC102.25 (DA3), IC141.34 (DA3); also elsewhere on the board
/IO/AYD4: IC102.24 (DA4), IC141.33 (DA4); also elsewhere on the board
/IO/AYD5: IC102.23 (DA5), IC141.32 (DA5); also elsewhere on the board
/IO/AYD6: IC102.22 (DA6), IC141.31 (DA6); also elsewhere on the board
/IO/AYD7: IC102.21 (DA7), IC141.30 (DA7); also elsewhere on the board
/IO/KB0: IC101.15 (P0); also elsewhere on the board
/IO/KB1: IC101.14 (P1); also elsewhere on the board
/IO/KB2: IC101.13 (P2); also elsewhere on the board
/IO/KB3: IC101.12 (P3); also elsewhere on the board
/Sound & Keyboard/AYIO0: CP2.3, IC102.14 (IOA0), IC141.21 (IOA0), J102.1, NR1.9 (R8)
/Sound & Keyboard/AYIO1: CP2.4, IC102.13 (IOA1), IC141.20 (IOA1), J102.2, NR1.8 (R7)
/Sound & Keyboard/AYIO2: CP2.5, IC102.12 (IOA2), IC141.19 (IOA2), J102.3, NR1.7 (R6)
/Sound & Keyboard/AYIO3: CP2.6, IC102.11 (IOA3), IC141.18 (IOA3), J102.4, NR1.6 (R5)
/Sound & Keyboard/AYIO4: CP2.7, IC102.10 (IOA4), IC141.17 (IOA4), J102.6, NR1.5 (R4)
/Sound & Keyboard/AYIO5: CP2.8, IC102.9 (IOA5), IC141.16 (IOA5), J102.7, NR1.4 (R3)
/Sound & Keyboard/AYIO6: CP2.9, IC102.8 (IOA6), IC141.15 (IOA6), J102.5, NR1.3 (R2)
/Sound & Keyboard/AYIO7: CP2.1, CP2.10, IC102.7 (IOA7), IC141.14 (IOA7), J102.9, NR1.2 (R1)
AYA: IC102.4 (A), IC141.4 (A), R115.1, R118.2, R119.2, R122.2
AYB: IC102.5 (B), IC141.3 (B), R116.1, R120.2, R123.2
AYBC1: IC102.20 (BC1), IC141.29 (BC1); also elsewhere on the board
AYBDIR: IC102.18 (BDIR), IC141.27 (BDIR); also elsewhere on the board
AYC: IC102.1 (C), IC141.38 (C), R114.1, R117.2, R121.2
CPU: IC102.15 (CLOCK), IC141.22 (CLOCK); also elsewhere on the board
GND: IC101.8 (GND), IC102.6 (GND), IC141.1 (GND), IC141.24 (~A9), J102.0 (GND), J103.1, R121.1, R122.1, R123.1; also elsewhere on the board
unnamed: CP2.2, IC101.11 (Q9), J102.8
unnamed: CP2.11, IC101.10 (Q8)
unnamed: CP2.12, IC101.9 (Q7)
unnamed: CP2.13, IC101.7 (Q6)
unnamed: CP2.14, IC101.6 (Q5)
unnamed: CP2.15, IC101.5 (Q4)
unnamed: CP2.16, IC101.4 (Q3)
unnamed: CP2.17, IC101.3 (Q2)
unnamed: CP2.18, IC101.2 (Q1)
unnamed: CP2.19, IC101.1 (Q0)
unnamed: J103.3 (Ground), R119.1, R120.1
unnamed: J103.2, R117.1, R118.1
RESET: IC102.16 (~RESET), IC141.23 (~RESET); also elsewhere on the board
SOUND: R114.2, R115.2, R116.2; also elsewhere on the board

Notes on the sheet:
AUDIO OUT

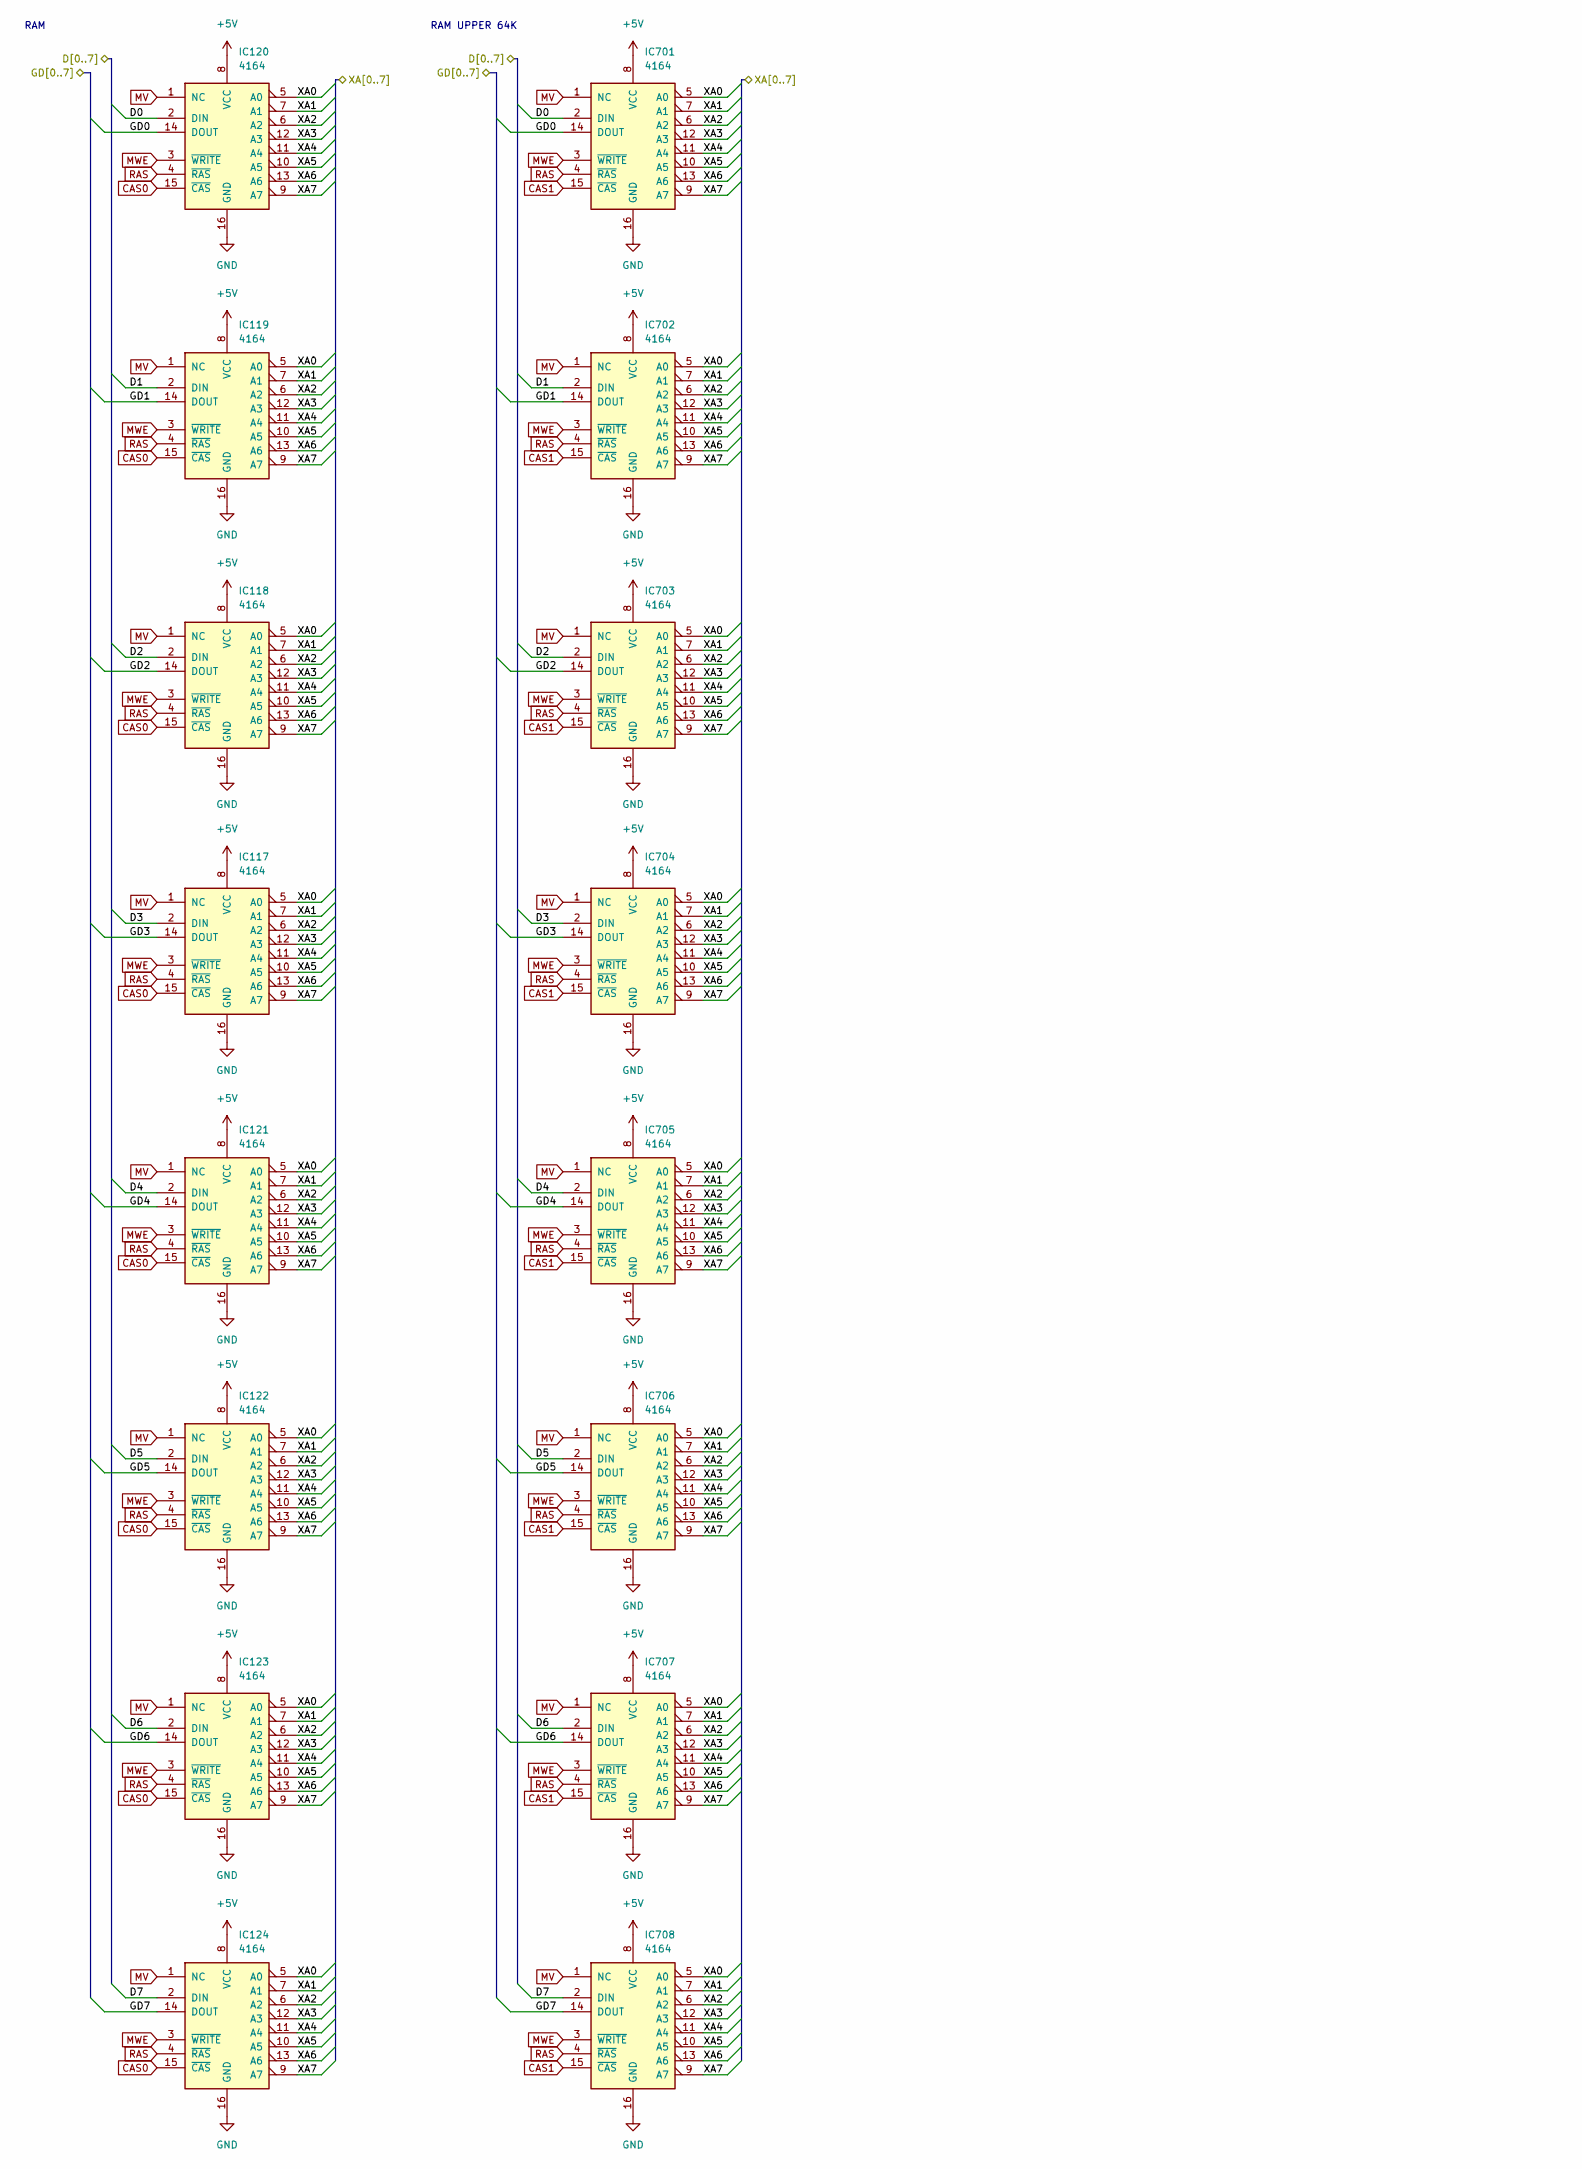
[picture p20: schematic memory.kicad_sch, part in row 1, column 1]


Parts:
IC103: AMS40009; DIP-28_W15.24mm; not fitted
IC117, IC118, IC119, IC120, IC121, IC122, IC123, IC124, IC701, IC702, IC703, IC704, IC705, IC706, IC707, IC708: 4164; DIP-16_W7.62mm
IC900: 40031; SOIC-20W_7.5x12.8mm_P1.27mm
IC901: 74LS08; SOIC-14_3.9x8.7mm_P1.27mm
IC1250: 39SF040; PLCC-32_THT-Socket
J900: RAM EXP; PinHeader_2x17_P2.54mm_Vertical; not fitted
LK5: LK5; PinHeader_1x02_P1.00mm_Vertical
LK6: LK6; PinHeader_1x02_P1.00mm_Vertical
LK8: LK8; PinHeader_1x02_P1.00mm_Vertical
R112: 2K2; R_0805_2012Metric; LCSC C114561
R156: 47R; R_0805_2012Metric; LCSC C114541
R160, R161: 47R; R_0805_2012Metric; LCSC C114245
R1250, R1251, R1252, R1253: 10K; R_0805_2012Metric
SW1250: SELECT; DIP-8_W7.62mm_Socket

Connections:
+5V: IC103.1 (VPP), IC103.28 (VCC), IC117.8 (VCC), IC118.8 (VCC), IC119.8 (VCC), IC120.8 (VCC), IC121.8 (VCC), IC122.8 (VCC), IC123.8 (VCC), IC124.8 (VCC), IC701.8 (VCC), IC702.8 (VCC), IC703.8 (VCC), IC704.8 (VCC), IC705.8 (VCC), IC706.8 (VCC), IC707.8 (VCC), IC708.8 (VCC), IC900.20 (VCC), IC901.14 (VCC), IC1250.31 (PGM), IC1250.32 (VCC), J900.27, J900.34, SW1250.5, SW1250.6, SW1250.7, SW1250.8; also elsewhere on the board
/CPU/A0: IC103.10 (A0), IC1250.12 (A0); also elsewhere on the board
/CPU/A1: IC103.9 (A1), IC1250.11 (A1); also elsewhere on the board
/CPU/A2: IC103.8 (A2), IC1250.10 (A2); also elsewhere on the board
/CPU/A3: IC103.7 (A3), IC1250.9 (A3); also elsewhere on the board
/CPU/A4: IC103.6 (A4), IC1250.8 (A4); also elsewhere on the board
/CPU/A5: IC103.5 (A5), IC1250.7 (A5); also elsewhere on the board
/CPU/A6: IC103.4 (A6), IC1250.6 (A6); also elsewhere on the board
/CPU/A7: IC103.3 (A7), IC1250.5 (A7); also elsewhere on the board
/CPU/A8: IC103.25 (A8), IC1250.27 (A8); also elsewhere on the board
/CPU/A9: IC103.24 (A9), IC1250.26 (A9); also elsewhere on the board
/CPU/A10: IC103.21 (A10), IC1250.23 (A10); also elsewhere on the board
/CPU/A11: IC103.23 (A11), IC1250.25 (A11); also elsewhere on the board
/CPU/A12: IC103.2 (A12), IC1250.4 (A12); also elsewhere on the board
/CPU/A13: IC103.26 (A13), IC1250.28 (A13); also elsewhere on the board
/CPU/A14: IC103.27 (A14), IC900.9 (A14), IC1250.29 (A14), LK5.1; also elsewhere on the board
/CPU/A15: IC900.8 (A15), LK6.1; also elsewhere on the board
/CPU/D0: IC103.11 (D0), IC120.2 (DIN), IC701.2 (DIN), IC900.2 (D0), IC1250.13 (D0), J900.9; also elsewhere on the board
/CPU/D1: IC103.12 (D1), IC119.2 (DIN), IC702.2 (DIN), IC900.5 (D1), IC1250.14 (D1), J900.10; also elsewhere on the board
/CPU/D2: IC103.13 (D2), IC118.2 (DIN), IC703.2 (DIN), IC900.6 (D2), IC1250.15 (D2), J900.11; also elsewhere on the board
/CPU/D3: IC103.15 (D3), IC117.2 (DIN), IC704.2 (DIN), IC1250.17 (D3), J900.12; also elsewhere on the board
/CPU/D4: IC103.16 (D4), IC121.2 (DIN), IC705.2 (DIN), IC1250.18 (D4), J900.13; also elsewhere on the board
/CPU/D5: IC103.17 (D5), IC122.2 (DIN), IC706.2 (DIN), IC1250.19 (D5), J900.14; also elsewhere on the board
/CPU/D6: IC103.18 (D6), IC123.2 (DIN), IC707.2 (DIN), IC901.1, IC1250.20 (D6), J900.15; also elsewhere on the board
/CPU/D7: IC103.19 (D7), IC124.2 (DIN), IC708.2 (DIN), IC901.2, IC1250.21 (D7), J900.16; also elsewhere on the board
/Gate Arrays/GD0: IC120.14 (DOUT), IC701.14 (DOUT), J900.19; also elsewhere on the board
/Gate Arrays/GD1: IC119.14 (DOUT), IC702.14 (DOUT), J900.20; also elsewhere on the board
/Gate Arrays/GD2: IC118.14 (DOUT), IC703.14 (DOUT), J900.21; also elsewhere on the board
/Gate Arrays/GD3: IC117.14 (DOUT), IC704.14 (DOUT), J900.22; also elsewhere on the board
/Gate Arrays/GD4: IC121.14 (DOUT), IC705.14 (DOUT), J900.23; also elsewhere on the board
/Gate Arrays/GD5: IC122.14 (DOUT), IC706.14 (DOUT), J900.24; also elsewhere on the board
/Gate Arrays/GD6: IC123.14 (DOUT), IC707.14 (DOUT), J900.25; also elsewhere on the board
/Gate Arrays/GD7: IC124.14 (DOUT), IC708.14 (DOUT), J900.26; also elsewhere on the board
/Memory/R15: IC1250.3 (A15), R1250.1, SW1250.1
/Memory/R16: IC1250.2 (A16), R1251.1, SW1250.2
/Memory/R17: IC1250.30 (A17), R1252.1, SW1250.3
/Memory/R18: IC1250.1 (A18), R1253.1, SW1250.4
/Memory/XA0: IC117.5 (A0), IC118.5 (A0), IC119.5 (A0), IC120.5 (A0), IC121.5 (A0), IC122.5 (A0), IC123.5 (A0), IC124.5 (A0), IC701.5 (A0), IC702.5 (A0), IC703.5 (A0), IC704.5 (A0), IC705.5 (A0), IC706.5 (A0), IC707.5 (A0), IC708.5 (A0), J900.1; also elsewhere on the board
/Memory/XA1: IC117.7 (A1), IC118.7 (A1), IC119.7 (A1), IC120.7 (A1), IC121.7 (A1), IC122.7 (A1), IC123.7 (A1), IC124.7 (A1), IC701.7 (A1), IC702.7 (A1), IC703.7 (A1), IC704.7 (A1), IC705.7 (A1), IC706.7 (A1), IC707.7 (A1), IC708.7 (A1), J900.2; also elsewhere on the board
/Memory/XA2: IC117.6 (A2), IC118.6 (A2), IC119.6 (A2), IC120.6 (A2), IC121.6 (A2), IC122.6 (A2), IC123.6 (A2), IC124.6 (A2), IC701.6 (A2), IC702.6 (A2), IC703.6 (A2), IC704.6 (A2), IC705.6 (A2), IC706.6 (A2), IC707.6 (A2), IC708.6 (A2), J900.3; also elsewhere on the board
/Memory/XA3: IC117.12 (A3), IC118.12 (A3), IC119.12 (A3), IC120.12 (A3), IC121.12 (A3), IC122.12 (A3), IC123.12 (A3), IC124.12 (A3), IC701.12 (A3), IC702.12 (A3), IC703.12 (A3), IC704.12 (A3), IC705.12 (A3), IC706.12 (A3), IC707.12 (A3), IC708.12 (A3), J900.4; also elsewhere on the board
/Memory/XA4: IC117.11 (A4), IC118.11 (A4), IC119.11 (A4), IC120.11 (A4), IC121.11 (A4), IC122.11 (A4), IC123.11 (A4), IC124.11 (A4), IC701.11 (A4), IC702.11 (A4), IC703.11 (A4), IC704.11 (A4), IC705.11 (A4), IC706.11 (A4), IC707.11 (A4), IC708.11 (A4), J900.5; also elsewhere on the board
/Memory/XA5: IC117.10 (A5), IC118.10 (A5), IC119.10 (A5), IC120.10 (A5), IC121.10 (A5), IC122.10 (A5), IC123.10 (A5), IC124.10 (A5), IC701.10 (A5), IC702.10 (A5), IC703.10 (A5), IC704.10 (A5), IC705.10 (A5), IC706.10 (A5), IC707.10 (A5), IC708.10 (A5), J900.6; also elsewhere on the board
/Memory/XA6: IC117.13 (A6), IC118.13 (A6), IC119.13 (A6), IC120.13 (A6), IC121.13 (A6), IC122.13 (A6), IC123.13 (A6), IC124.13 (A6), IC701.13 (A6), IC702.13 (A6), IC703.13 (A6), IC704.13 (A6), IC705.13 (A6), IC706.13 (A6), IC707.13 (A6), IC708.13 (A6), J900.7; also elsewhere on the board
/Memory/XA7: IC117.9 (A7), IC118.9 (A7), IC119.9 (A7), IC120.9 (A7), IC121.9 (A7), IC122.9 (A7), IC123.9 (A7), IC124.9 (A7), IC701.9 (A7), IC702.9 (A7), IC703.9 (A7), IC704.9 (A7), IC705.9 (A7), IC706.9 (A7), IC707.9 (A7), IC708.9 (A7), J900.8; also elsewhere on the board
A14OUT: IC900.19 (A14out), LK5.2; also elsewhere on the board
A15OUT: IC900.12 (A15out), LK6.2; also elsewhere on the board
CAS: IC900.7 (NCAS), LK8.1; also elsewhere on the board
CAS0: IC117.15 (~CAS), IC118.15 (~CAS), IC119.15 (~CAS), IC120.15 (~CAS), IC121.15 (~CAS), IC122.15 (~CAS), IC123.15 (~CAS), IC124.15 (~CAS), J900.29, LK8.2, R161.2
CAS1: IC701.15 (~CAS), IC702.15 (~CAS), IC703.15 (~CAS), IC704.15 (~CAS), IC705.15 (~CAS), IC706.15 (~CAS), IC707.15 (~CAS), IC708.15 (~CAS), J900.28, R160.2
CPU: IC900.11 (~CPU); also elsewhere on the board
D6ANDD7: IC900.1 (D7D6), IC901.3
GND: IC103.14 (GND), IC117.16 (GND), IC118.16 (GND), IC119.16 (GND), IC120.16 (GND), IC121.16 (GND), IC122.16 (GND), IC123.16 (GND), IC124.16 (GND), IC701.16 (GND), IC702.16 (GND), IC703.16 (GND), IC704.16 (GND), IC705.16 (GND), IC706.16 (GND), IC707.16 (GND), IC708.16 (GND), IC900.10 (GND), IC901.4, IC901.5, IC901.7 (GND), IC901.9, IC901.10, IC901.12, IC901.13, IC1250.16 (GND), J900.17, J900.18, R112.2, R1250.2, R1251.2, R1252.2, R1253.2; also elsewhere on the board
IOWR: IC900.18 (~IOWR); also elsewhere on the board
MV: IC117.1 (NC), IC118.1 (NC), IC119.1 (NC), IC120.1 (NC), IC121.1 (NC), IC122.1 (NC), IC123.1 (NC), IC124.1 (NC), IC701.1 (NC), IC702.1 (NC), IC703.1 (NC), IC704.1 (NC), IC705.1 (NC), IC706.1 (NC), IC707.1 (NC), IC708.1 (NC)
MWE: IC117.3 (~WRITE), IC118.3 (~WRITE), IC119.3 (~WRITE), IC120.3 (~WRITE), IC121.3 (~WRITE), IC122.3 (~WRITE), IC123.3 (~WRITE), IC124.3 (~WRITE), IC701.3 (~WRITE), IC702.3 (~WRITE), IC703.3 (~WRITE), IC704.3 (~WRITE), IC705.3 (~WRITE), IC706.3 (~WRITE), IC707.3 (~WRITE), IC708.3 (~WRITE), J900.31; also elsewhere on the board
unnamed: IC900.17 (~CAS0), R161.1
unnamed: IC900.16 (~CAS1), R160.1
RAMDIS: IC900.4 (RAMDIS); also elsewhere on the board
RAS: IC117.4 (~RAS), IC118.4 (~RAS), IC119.4 (~RAS), IC120.4 (~RAS), IC121.4 (~RAS), IC122.4 (~RAS), IC123.4 (~RAS), IC124.4 (~RAS), IC701.4 (~RAS), IC702.4 (~RAS), IC703.4 (~RAS), IC704.4 (~RAS), IC705.4 (~RAS), IC706.4 (~RAS), IC707.4 (~RAS), IC708.4 (~RAS), J900.30; also elsewhere on the board
RESET: IC900.3 (~RESET); also elsewhere on the board
ROMCE: IC103.20 (~CE), IC1250.22 (CE), R156.1
ROMDIS: IC103.22 (~OE), IC1250.24 (OE), R112.1; also elsewhere on the board
ROMEN: R156.2; also elsewhere on the board

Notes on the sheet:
RAM UPPER 64K
RAM
ROM


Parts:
IC104, IC105, IC109, IC113: 74LS153D; SOIC-16_3.9x9.9mm_P1.27mm
R146, R147, R148, R149, R150, R151, R152, R153: 82R; R_0805_2012Metric; LCSC C114245
R157, R158: 680R; R_0805_2012Metric; LCSC C114549

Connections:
+5V: IC104.16 (VCC), IC105.16 (VCC), IC109.16 (VCC), IC113.16 (VCC), R158.2; also elsewhere on the board
/CPU/A0: IC105.6 (I0a); also elsewhere on the board
/CPU/A1: IC105.5 (I1a); also elsewhere on the board
/CPU/A2: IC105.11 (I1b); also elsewhere on the board
/CPU/A3: IC113.5 (I1a); also elsewhere on the board
/CPU/A4: IC113.11 (I1b); also elsewhere on the board
/CPU/A5: IC104.5 (I1a); also elsewhere on the board
/CPU/A6: IC104.11 (I1b); also elsewhere on the board
/CPU/A7: IC109.5 (I1a); also elsewhere on the board
/CPU/A8: IC109.11 (I1b); also elsewhere on the board
/CPU/A9: IC105.10 (I0b); also elsewhere on the board
/CPU/A10: IC113.6 (I0a); also elsewhere on the board
/CPU/A11: IC113.10 (I0b); also elsewhere on the board
/CPU/A12: IC104.6 (I0a); also elsewhere on the board
/CPU/A13: IC104.10 (I0b); also elsewhere on the board
/Memory/XA0: R149.2; also elsewhere on the board
/Memory/XA1: R148.2; also elsewhere on the board
/Memory/XA2: R153.2; also elsewhere on the board
/Memory/XA3: R152.2; also elsewhere on the board
/Memory/XA4: R147.2; also elsewhere on the board
/Memory/XA5: R146.2, R158.1; also elsewhere on the board
/Memory/XA6: R151.2; also elsewhere on the board
/Memory/XA7: R150.2; also elsewhere on the board
/Multiplex/MA0: IC105.3 (I3a); also elsewhere on the board
/Multiplex/MA1: IC105.13 (I3b); also elsewhere on the board
/Multiplex/MA2: IC113.3 (I3a); also elsewhere on the board
/Multiplex/MA3: IC113.13 (I3b); also elsewhere on the board
/Multiplex/MA4: IC104.3 (I3a); also elsewhere on the board
/Multiplex/MA5: IC104.13 (I3b); also elsewhere on the board
/Multiplex/MA6: IC109.3 (I3a); also elsewhere on the board
/Multiplex/MA7: IC109.13 (I3b); also elsewhere on the board
/Multiplex/MA8: IC105.12 (I2b); also elsewhere on the board
/Multiplex/MA9: IC113.4 (I2a); also elsewhere on the board
/Multiplex/MA12: IC109.4 (I2a); also elsewhere on the board
/Multiplex/MA13: IC109.12 (I2b); also elsewhere on the board
A14OUT: IC109.6 (I0a); also elsewhere on the board
A15OUT: IC109.10 (I0b); also elsewhere on the board
CASAD: IC104.14 (S0), IC105.14 (S0), IC109.14 (S0), IC113.14 (S0), R157.2; also elsewhere on the board
CCLK: IC105.4 (I2a); also elsewhere on the board
CPU: IC104.2 (S1), IC105.2 (S1), IC109.2 (S1), IC113.2 (S1); also elsewhere on the board
GND: IC104.1 (Ea), IC104.8 (GND), IC104.15 (Eb), IC105.1 (Ea), IC105.8 (GND), IC105.15 (Eb), IC109.1 (Ea), IC109.8 (GND), IC109.15 (Eb), IC113.1 (Ea), IC113.8 (GND), IC113.15 (Eb); also elsewhere on the board
unnamed: IC104.7 (Za), R146.1
unnamed: IC104.9 (Zb), R147.1, R157.1
unnamed: IC105.7 (Za), R148.1
unnamed: IC105.9 (Zb), R149.1
unnamed: IC109.7 (Za), R150.1
unnamed: IC109.9 (Zb), R151.1
unnamed: IC113.7 (Za), R152.1
unnamed: IC113.9 (Zb), R153.1
RA0: IC113.12 (I2b); also elsewhere on the board
RA1: IC104.4 (I2a); also elsewhere on the board
RA2: IC104.12 (I2b); also elsewhere on the board



Board: 2 copper layers, 246.0 x 85.0 mm, 164 parts (4 on the bottom side), 190 nets.

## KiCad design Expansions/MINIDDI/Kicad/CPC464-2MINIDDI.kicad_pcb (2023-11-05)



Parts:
C401: 100uF; CP_Radial_D6.3mm_P2.50mm
C403, C404, C405, C406, C407, C408, C409, C410, C411, C412, C413, C414: 100nF; C_0805_2012Metric
C451, C452: 7pF; C_0805_2012Metric; LCSC C1834
C453: 47nF; C_0805_2012Metric; LCSC C1834
C454: 1nF; C_0805_2012Metric; LCSC C1834
C455: 10nF; C_0805_2012Metric; LCSC C1834
CD402: PC; IDC-Header_2x17_P2.54mm_Vertical
CE401, CE402: 50Pin Expansion Connector; EXPANSION_IDC_ANONYMISED
D401: 1N4148; D_SOD-123
D450: MOTOR; LED_1206_3216Metric
D451: POWER; LED_1206_3216Metric
H1, H7: MountingHole; MountingHole_2.7mm_M2.5_ISO14580_Pad
IC401: 765FDC; DIP-40_W15.24mm
IC403: 74HC240; SOIC-20W_7.5x12.8mm_P1.27mm
IC404: ROM 27128; DIP-28_W15.24mm
IC405: 74LS08; SOIC-14_3.9x8.7mm_P1.27mm
IC406, IC408: 74LS38; SOIC-14_3.9x8.7mm_P1.27mm
IC407: 74LS32; SOIC-14_3.9x8.7mm_P1.27mm
IC409: 74LS136; SOIC-14_3.9x8.7mm_P1.27mm
IC410: 74LS132; SOIC-14_3.9x8.7mm_P1.27mm
IC411: 74LS27; SOIC-14_3.9x8.7mm_P1.27mm
IC412: 74LS74; SOIC-14_3.9x8.7mm_P1.27mm
IC451: SED9420CAC; DIP-24_W15.24mm
LK401: LK401; PinHeader_1x02_P2.54mm_Vertical
LK402: LK402; PinHeader_1x02_P2.54mm_Vertical
R402, R403, R404, R405, R406, R452, R458: 680R; R_0805_2012Metric
R411, R412, R416, R459: 1K; R_0805_2012Metric
R414, R453: 2K2; R_0805_2012Metric
R417: 10K; R_0805_2012Metric
R418: 150R; R_0805_2012Metric
R451: 10M; R_0805_2012Metric; LCSC C309665
R454: 68K; R_0805_2012Metric
R455: 33K; R_0805_2012Metric
R456: 1K5; R_0805_2012Metric
R457: 6K8; R_0805_2012Metric
X451: 16MHz; Crystal_HC49-U_Vertical

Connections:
5V: C401.1, C403.1, C404.1, C405.1, C406.1, C407.1, C408.1, C409.1, C410.1, C411.1, C412.1, C413.1, C414.1, CE401.27, CE402.27, IC401.40 (VCC), IC403.20 (VCC), IC404.1 (VPP), IC404.27 (~PGM), IC404.28 (VCC), IC405.14 (VCC), IC406.14 (VCC), IC407.14 (VCC), IC408.14 (VCC), IC409.14 (VCC), IC410.14 (VCC), IC411.14 (VCC), IC412.14 (VCC), IC451.10 (MFM/FM), IC451.11 (MIN/STD), IC451.24 (VCC), R402.1, R403.1, R404.1, R405.1, R406.2, R411.2, R412.1, R414.2, R416.2, R417.2, R452.2, R453.2, R459.2
!R: IC403.6, IC412.13 (~R), R417.1, R418.1
/A0: CE401.18, CE402.18, IC401.5 (A0), IC404.10 (A0)
/A1: CE401.17, CE402.17, IC404.9 (A1)
/A2: CE401.16, CE402.16, IC404.8 (A2)
/A3: CE401.15, CE402.15, IC404.7 (A3)
/A4: CE401.14, CE402.14, IC404.6 (A4)
/A5: CE401.13, CE402.13, IC404.5 (A5)
/A6: CE401.12, CE402.12, IC404.4 (A6)
/A7: CE401.11, CE402.11, IC404.3 (A7), IC407.5
/A8: CE401.10, CE402.10, IC404.25 (A8), IC410.9, IC411.9
/A9: CE401.9, CE402.9, IC404.24 (A9)
/A10: CE401.8, CE402.8, IC404.21 (A10), IC407.4
/A11: CE401.7, CE402.7, IC404.23 (A11)
/A12: CE401.6, CE402.6, IC404.2 (A12)
/A13: CE401.5, CE402.5, IC404.26 (A13), IC407.9
/A14: CE401.4, CE402.4
/A15: CE401.3, CE402.3, IC405.1, IC410.5
/D0: CE401.26, CE402.26, IC401.6 (D0), IC404.11 (D0), IC409.9, IC412.12 (D)
/D1: CE401.25, CE402.25, IC401.7 (D1), IC404.12 (D1), IC409.12
/D2: CE401.24, CE402.24, IC401.8 (D2), IC404.13 (D2), IC409.1
/D3: CE401.23, CE402.23, IC401.9 (D3), IC404.15 (D3), IC411.13
/D4: CE401.22, CE402.22, IC401.10 (D4), IC404.16 (D4), IC411.2
/D5: CE401.21, CE402.21, IC401.11 (D5), IC404.17 (D5), IC411.5
/D6: CE401.20, CE402.20, IC401.12 (D6), IC404.18 (D6), IC411.4
/D7: CE401.19, CE402.19, IC401.13 (D7), IC404.19 (D7), IC411.3
A100: CE401.50, CE402.50
BUS: CE401.40, CE402.40
BUSAK: CE401.38, CE402.38
BUSRQ: CE401.37, CE402.37
CURSOR: CE401.46, CE402.46
EXP: CE401.48, CE402.48, IC409.2, IC409.10, IC409.13, LK401.1
GND: C401.2, C403.2, C404.2, C405.2, C406.2, C407.2, C408.2, C409.2, C410.2, C411.2, C412.2, C413.2, C414.2, C451.2, C452.2, C453.1, C455.1, CD402.1, CD402.3, CD402.5, CD402.7, CD402.9, CD402.11, CD402.13, CD402.15, CD402.17, CD402.19, CD402.21, CD402.23, CD402.25, CD402.27, CD402.29, CD402.31, CD402.33, CE401.2, CE401.49, CE402.2, CE402.49, D450.1 (K), D451.1 (K), H1.1, H7.1, IC401.20 (GND), IC403.1, IC403.10 (GND), IC403.19, IC404.14 (GND), IC405.7 (GND), IC405.12, IC405.13, IC406.7 (GND), IC407.7 (GND), IC408.7 (GND), IC409.7 (GND), IC410.7 (GND), IC411.7 (GND), IC412.7 (GND), IC451.12 (GND1), IC451.13 (GND2), LK401.2, LK402.2
HALT: CE401.34, CE402.34
IC404EN: IC404.22 (~OE), IC410.6
INT: CE401.35, CE402.35
IORQ: CE401.31, CE402.31, IC407.1, IC407.13
LPEN: CE401.47, CE402.47
M1: CE401.29, CE402.29
MREQ: CE401.28, CE402.28
NMI: CE401.36, CE402.36
unnamed: C451.1, IC451.1 (OSC1), R451.1, X451.2
unnamed: C452.1, IC451.2 (OSC2), R451.2, X451.1
unnamed: C453.2, IC451.15 (OFFSET)
unnamed: C454.1, IC451.14 (CONTROL), R455.1, R456.1, R457.1
unnamed: C454.2, R454.1
unnamed: C455.2, R457.2
unnamed: D401.2 (A), IC405.3, R406.1
unnamed: D450.2 (A), R458.1
unnamed: D451.2 (A), R459.1
unnamed: IC401.17 (INDEX), IC403.16
unnamed: IC401.25 (WE), IC408.13
unnamed: IC401.27 (SIDE), IC406.12, IC406.13
unnamed: IC401.29 (US0), IC406.9, IC406.10
unnamed: IC401.33 (FLTR/TRK0), IC405.6
unnamed: IC401.34 (WPRT/2SIDE), IC403.7
unnamed: IC401.35 (READY), IC403.5, IC408.12
unnamed: IC401.37 (FLTR/STEP), IC405.9
unnamed: IC401.38 (LCT/DIR), IC406.1, IC406.2
unnamed: IC401.39 (~RW/SEEK), IC405.5, IC405.10
unnamed: IC403.3, R458.2
unnamed: IC403.8, IC407.6, IC411.11, R416.1
unnamed: IC403.9, IC405.4
unnamed: IC403.12, IC410.10
unnamed: IC403.17, IC412.8 (~Q)
unnamed: IC403.18, IC451.7 (RD_DATA)
unnamed: IC405.8, IC408.9, IC408.10
unnamed: IC407.8, IC412.3 (C)
unnamed: IC408.1, IC408.2, IC412.9 (Q)
unnamed: IC410.11, IC411.1
unnamed: IC410.12, IC411.6
unnamed: IC411.8, IC412.11 (C)
unnamed: IC411.12, IC412.2 (D)
unnamed: IC451.5 (DRQ), R453.1
unnamed: IC451.16 (LPF1), R456.2
unnamed: IC451.17 (LPF2), R454.2, R455.2
RAMDIS: CE401.45, CE402.45
RAMRD: CE401.44, CE402.44
RD: CE401.32, CE402.32, IC407.2
READY: CE401.39, CE402.39
RESET: CE401.41, CE402.41, R418.2
RFSH: CE401.30, CE402.30
ROMDIS: CE401.43, CE402.43, D401.1 (K)
ROMEN: CE401.42, CE402.42, IC404.20 (~CE)
SELECT: IC405.2, IC410.4, IC412.5 (Q)
SOUND: CE401.1, CE402.1
WR: CE401.33, CE402.33, IC407.12
fDIR: CD402.18, IC406.3
fDRIVE0: CD402.10, IC406.6
fDRIVE1: CD402.12, IC406.4, IC406.5, IC406.8, R414.1
fINDEX: CD402.8, IC403.4, R403.2
fMOTOR1: CD402.16, IC408.3
fREAD: CD402.30, IC403.2, R452.1
fREADY: CD402.34, IC403.15, LK402.1, R402.2
fSIDE1: CD402.32, IC406.11
fSTEP: CD402.20, IC408.8
fTRACK0: CD402.26, IC403.11, R405.2
fWDATA: CD402.22, IC408.6
fWGATE: CD402.24, IC408.11
fWRITEPROT: CD402.28, IC403.13, R404.2
uCLK: IC401.19 (CLK), IC451.3 (CLK1)
uCS: IC401.4 (~CS), IC410.8
uDACK: IC401.15 (~DACK), IC412.1 (~R), IC412.4 (~S), IC412.10 (~S), R412.2
uDACK2K: IC409.3, IC409.8, IC409.11, IC410.13, R411.1
uMFM: IC401.26 (MFM)
uPS0: IC401.32 (PS0)
uPS1: IC401.31 (PS1)
uRD: IC401.2 (~RD), IC407.3
uRDATA: IC401.23 (RDATA), IC451.9 (DATA)
uRESET: IC401.1 (RESET), IC401.16 (TC), IC403.14
uSYNC: IC401.24 (SYNC), IC451.6 (SYNC)
uWCLK: IC401.21 (WCLK), IC451.19 (WCLK)
uWDATA: IC401.30 (WDATA), IC408.4, IC408.5
uWINDOW: IC401.22 (WINDOW), IC451.8 (WINDOW)
uWR: IC401.3 (~WR), IC407.10, IC407.11, IC411.10

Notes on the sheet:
sync all the time or on int?
Votes: +3 7pF ppc640 7pf


Board: 2 copper layers, 93.4 x 80.2 mm, 61 parts (0 on the bottom side), 112 nets.

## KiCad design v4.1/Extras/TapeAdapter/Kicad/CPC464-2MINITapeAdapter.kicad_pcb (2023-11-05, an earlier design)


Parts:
C317: 4.7nF; C_Disc_D4.3mm_W1.9mm_P5.00mm
C351: 47uF; CP_Radial_D4.0mm_P2.00mm
C353: TAPE PORT; PinHeader_1x08_P2.54mm_Vertical
H5: MountingHole; MountingHole_2.7mm_M2.5_ISO14580_Pad
J350: MIC; STEREO
J351: EAR; STEREO
Q350: BC547; TO92_WIDE
R310, R314: 10K; R_Axial_DIN0204_L3.6mm_D1.6mm_P7.62mm_Horizontal
R313, R315: 4K7; R_Axial_DIN0204_L3.6mm_D1.6mm_P7.62mm_Horizontal
R316: 1K; R_Axial_DIN0204_L3.6mm_D1.6mm_P7.62mm_Horizontal
R317: 470K; R_Axial_DIN0204_L3.6mm_D1.6mm_P7.62mm_Horizontal
R318: 2K2; R_Axial_DIN0204_L3.6mm_D1.6mm_P7.62mm_Horizontal

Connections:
+5V: C353.1, C353.3, C353.6, Q350.1 (C), R310.2, R315.2
DATAIN: C353.5, R318.1
DATAOUT: C317.2, C353.4, R315.1
EAR: C351.1, J351.2
GND: C353.2, H5.1, J350.1, J351.1, R313.1, R314.1, R316.2
MIC: J350.2, R316.1, R317.2
MOTOR: C353.8
unnamed: C317.1, R317.1
unnamed: Q350.3 (E), R314.2, R318.2
unnamed: C351.2, Q350.2 (B), R310.1, R313.2
SOUND: C353.7

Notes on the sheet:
TO CASSETTE
FROM CASSETTE


Board: 2 copper layers, 25.7 x 43.2 mm, 14 parts (0 on the bottom side), 9 nets.

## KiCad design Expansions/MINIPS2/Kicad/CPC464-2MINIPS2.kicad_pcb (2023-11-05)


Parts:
C800, C801: 20pF; C_0805_2012Metric
C802, C806, C807: 100nF; C_0805_2012Metric
CP002: CPC464-2MINI; PinHeader_1x20_P2.54mm_Vertical
D810: POWER; LED_1206_3216Metric
H9: Smaller Keyboard Hole; MountingHole_2.2mm_M2_DIN965_Pad
IC800: ATmega328P-A; TQFP-32_7x7mm_P0.8mm
IC803: MT8816AF1; TQFP-44_10x10mm_P0.8mm
J105: CPCMINIPWR; PinHeader_1x03_P2.54mm_Vertical
J800: ISP6; PinHeader_2x03_P2.54mm_Vertical
J804: PS/2; Connector_Mini-DIN_Female_6Pin_2rows
Q800: BCV49; SOT-89-3
R804: 10K; R_0805_2012Metric
R808: 1K5; R_0805_2012Metric
R809: 1K; R_0805_2012Metric
Y800: 16MHz; Crystal_HC49-U_Vertical

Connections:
!RST: J105.1, Q800.2 (C)
+5V: C806.2, C807.2, IC800.4 (VCC), IC800.6 (VCC), IC800.18 (AVCC), IC803.34 (CS), IC803.38 (VCC), J105.2, J800.2, J804.4, R804.1, R809.2
/AA1: IC800.24 (PC1)
/AA2: IC800.25 (PC2)
/AA3: IC800.26 (PC3)
/AA4: IC800.27 (PC4)
/AA5: IC800.28 (PC5)
/AA6: IC800.19 (ADC6)
/AA7: IC800.22 (ADC7)
/AD0: IC800.30 (PD0)
/AD1: IC800.31 (PD1)
/COL0: CP002.11, IC803.31 (X0)
/COL1: CP002.12, IC803.30 (X1)
/COL2: CP002.13, IC803.29 (X2)
/COL3: CP002.14, IC803.28 (X3)
/COL4: CP002.15, IC803.27 (X4)
/COL5: CP002.16, IC803.26 (X5)
/COL6: CP002.17, IC803.4 (X6)
/COL7: CP002.18, IC803.5 (X7)
/COL8: CP002.19, IC803.6 (X8)
/COL9: CP002.2, IC803.7 (X9)
/COL10: IC803.8 (X10)
/COL11: IC803.9 (X11)
/COL12: IC803.25 (X12)
/COL13: IC803.24 (X13)
/COL14: IC803.2 (X14)
/COL15: IC803.3 (X15)
/ROW0: CP002.3, IC803.32 (Y0)
/ROW1: CP002.4, IC803.35 (Y1)
/ROW2: CP002.5, IC803.37 (Y2)
/ROW3: CP002.6, IC803.39 (Y3)
/ROW4: CP002.7, IC803.17 (Y4)
/ROW5: CP002.8, IC803.15 (Y5)
/ROW6: CP002.9, IC803.13 (Y6)
/ROW7: CP002.1, CP002.10, IC803.10 (Y7)
ADMOSI: IC800.15 (PB3), IC803.43 (AX3), J800.4
ADRESET: IC800.29 (~RESET/PC6), J800.5, R804.2
ADSCK: IC800.17 (PB5), IC803.42 (RESET), J800.3
AX0: IC800.14 (PB2), IC803.44 (AX0)
AX1: IC800.13 (PB1), IC803.18 (AX1)
AX2: IC800.12 (PB0), IC803.19 (AX2)
AY0: IC800.11 (PD7), IC803.20 (AY0)
AY1: IC800.10 (PD6), IC803.21 (AY1)
AY2: IC800.9 (PD5), IC803.40 (AY2)
BREAK: IC800.23 (PC0), R808.2
GND: C800.2, C801.2, C802.2, C806.1, C807.1, D810.1 (K), H9.1, IC800.3 (GND), IC800.5 (GND), IC800.21 (GND), IC803.12 (VSS), IC803.16 (VEE), J105.3, J800.6, J804.3, J804.7, Q800.3 (E)
MTDATA: IC800.32 (PD2), IC803.36 (DATA)
MTSTROBE: IC800.2 (PD4), IC803.14 (STROBE)
unnamed: C800.1, IC800.7 (XTAL1/PB6), Y800.1
unnamed: C801.1, IC800.8 (XTAL2/PB7), Y800.2
unnamed: C802.1, IC800.20 (AREF)
unnamed: D810.2 (A), R809.1
unnamed: Q800.1 (B), R808.1
PS2-CLK: IC800.1 (PD3), J804.5
PS2-DATA: IC800.16 (PB4), J800.1, J804.1


Board: 2 copper layers, 24.7 x 67.6 mm, 18 parts (0 on the bottom side), 40 nets.

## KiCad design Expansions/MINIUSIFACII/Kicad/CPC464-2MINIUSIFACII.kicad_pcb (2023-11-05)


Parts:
C1050, C1062: 100nF; C_0805_2012Metric
C1051: 100uF; CP_Radial_D5.0mm_P2.50mm
D1050: 5V POWER; LED_1206_3216Metric
D1051: 3.3V POWER; LED_1206_3216Metric
H1, H7: MountingHole; MountingHole_2.7mm_M2.5_ISO14580_Pad
R1050: 1K; R_0805_2012Metric
R1051: 470R; R_0805_2012Metric

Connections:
+3.3V: C1062.1, R1051.2; also elsewhere on the board
+5V: C1050.1, C1051.1, R1050.2; also elsewhere on the board
GND: C1050.2, C1051.2, C1062.2, D1050.1 (K), D1051.1 (K), H1.1, H7.1; also elsewhere on the board
unnamed: D1050.2 (A), R1050.1
unnamed: D1051.2 (A), R1051.1

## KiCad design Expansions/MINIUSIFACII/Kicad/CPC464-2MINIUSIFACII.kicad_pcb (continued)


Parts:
D1060: ACT; LED_1206_3216Metric
IC1061: CH376S; SOIC-28W_7.5x17.9mm_P1.27mm
J1060: USB; USB_A_Molex_67643_Horizontal
J1061: Micro_SD_Card; microSD_HC_Hirose_DM3AT-SF-PEJM5
J1062: USB External; PinSocket_2x05_P2.54mm_Horizontal
R1060: 1K; R_0805_2012Metric
R1061, R1062: 1R; R_0805_2012Metric
R1063: 10K; R_0805_2012Metric
Y1060: 12MHz; Crystal_HC49-U_Vertical

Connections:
+3.3V: D1060.2 (A), IC1061.9 (V3), IC1061.28 (VCC), R1062.2, R1063.2; also elsewhere on the board
+5V: R1061.2; also elsewhere on the board
GND: IC1061.12 (GND), J1060.4 (GND), J1060.5 (Shield), J1061.6 (VSS), J1061.9 (SHIELD), J1061.10 (SHIELD), J1061.11 (SHIELD), J1062.7, J1062.8; also elsewhere on the board
unnamed: D1060.1 (K), R1060.1
unnamed: IC1061.7 (SD_DI), J1061.7 (DAT0)
unnamed: IC1061.13 (XI), Y1060.2
unnamed: IC1061.14 (XO), Y1060.1
unnamed: IC1061.23 (SD_CS), J1061.2 (DAT3/CD)
unnamed: IC1061.24 (~ACT), R1060.2
unnamed: IC1061.25 (SD_DO), J1061.3 (CMD)
unnamed: IC1061.26 (SD_CK), J1061.5 (CLK)
unnamed: J1060.1 (VBUS), J1062.1, J1062.2, R1061.1
unnamed: J1061.1 (DAT2), J1061.8 (DAT1), R1063.1
unnamed: J1061.4 (VDD), R1062.1
UDN: IC1061.11 (UD-), J1060.2 (D-), J1062.3, J1062.4
UDP: IC1061.10 (UD+), J1060.3 (D+), J1062.5, J1062.6
URX: IC1061.5 (TXD); also elsewhere on the board
UTX: IC1061.6 (RXD); also elsewhere on the board


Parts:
CE1050, CE1051: 50Pin Expansion Connector; EXPANSION_IDC_ANONYMISED

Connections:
+5V: CE1050.27, CE1051.27; also elsewhere on the board
/Expansion Ports/A0: CE1050.18, CE1051.18; also elsewhere on the board
/Expansion Ports/A1: CE1050.17, CE1051.17; also elsewhere on the board
/Expansion Ports/A2: CE1050.16, CE1051.16; also elsewhere on the board
/Expansion Ports/A3: CE1050.15, CE1051.15; also elsewhere on the board
/Expansion Ports/A4: CE1050.14, CE1051.14; also elsewhere on the board
/Expansion Ports/A5: CE1050.13, CE1051.13; also elsewhere on the board
/Expansion Ports/A6: CE1050.12, CE1051.12; also elsewhere on the board
/Expansion Ports/A7: CE1050.11, CE1051.11; also elsewhere on the board
/Expansion Ports/A8: CE1050.10, CE1051.10; also elsewhere on the board
/Expansion Ports/A9: CE1050.9, CE1051.9; also elsewhere on the board
/Expansion Ports/A10: CE1050.8, CE1051.8; also elsewhere on the board
/Expansion Ports/A11: CE1050.7, CE1051.7; also elsewhere on the board
/Expansion Ports/A12: CE1050.6, CE1051.6; also elsewhere on the board
/Expansion Ports/A13: CE1050.5, CE1051.5; also elsewhere on the board
/Expansion Ports/A14: CE1050.4, CE1051.4; also elsewhere on the board
/Expansion Ports/A15: CE1050.3, CE1051.3; also elsewhere on the board
/Expansion Ports/D0: CE1050.26, CE1051.26; also elsewhere on the board
/Expansion Ports/D1: CE1050.25, CE1051.25; also elsewhere on the board
/Expansion Ports/D2: CE1050.24, CE1051.24; also elsewhere on the board
/Expansion Ports/D3: CE1050.23, CE1051.23; also elsewhere on the board
/Expansion Ports/D4: CE1050.22, CE1051.22; also elsewhere on the board
/Expansion Ports/D5: CE1050.21, CE1051.21; also elsewhere on the board
/Expansion Ports/D6: CE1050.20, CE1051.20; also elsewhere on the board
/Expansion Ports/D7: CE1050.19, CE1051.19; also elsewhere on the board
A100: CE1050.50, CE1051.50
BUS: CE1050.40, CE1051.40; also elsewhere on the board
BUSAK: CE1050.38, CE1051.38
BUSRQ: CE1050.37, CE1051.37
CURSOR: CE1050.46, CE1051.46
EXP: CE1050.48, CE1051.48
GND: CE1050.2, CE1050.49, CE1051.2, CE1051.49; also elsewhere on the board
HALT: CE1050.34, CE1051.34
INT: CE1050.35, CE1051.35
IORQ: CE1050.31, CE1051.31; also elsewhere on the board
LPEN: CE1050.47, CE1051.47
M1: CE1050.29, CE1051.29; also elsewhere on the board
MREQ: CE1050.28, CE1051.28
NMI: CE1050.36, CE1051.36
RAMDIS: CE1050.45, CE1051.45
RAMRD: CE1050.44, CE1051.44
RD: CE1050.32, CE1051.32; also elsewhere on the board
READY: CE1050.39, CE1051.39; also elsewhere on the board
RESET: CE1050.41, CE1051.41
RFSH: CE1050.30, CE1051.30
ROMDIS: CE1050.43, CE1051.43; also elsewhere on the board
ROMEN: CE1050.42, CE1051.42; also elsewhere on the board
SOUND: CE1050.1, CE1051.1
WR: CE1050.33, CE1051.33


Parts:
C1060, C1061: 10uF; CP_EIA-3216-18_Kemet-A
IC1060: LM1117-3.3; SOT-223-3_TabPin2
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

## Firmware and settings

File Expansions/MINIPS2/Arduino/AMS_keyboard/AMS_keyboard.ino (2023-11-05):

/*
  AMSkeyboard - Amstrad Keyboard Library
  Adapted by Ian Cudlip
  v1 01/01/2023

  Based on C64keyboard - Commodore Keyboard library by Hartland PC LLC
  Copyright (c) 2022 Hartland PC LLC
  Written by Robert VanHazinga

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
  You should have received a copy of the GNU Lesser General Public
  License along with this library; if not, write to the Free Software
  Foundation, Inc., 51 Franklin St, Fifth Floor, Boston, MA  02110-1301  USA
*/

#include <PS2KeyAdvanced.h>
#include "AMSkeyboard.h"

PS2KeyAdvanced keyboard;
AMSkeyboard ckey;
static volatile uint8_t  currkeymap = 1, flags ;
static const AMSKeymap_t *keymap = NULL;
static volatile bool lshift=false, rshift=false, capslock=false, amsbreak=false;

void setup() {
 // Configure the keyboard library
 keyboard.begin( DATA_PIN, IRQ_PIN );
 keyboard.setNoRepeat (1);
 keyboard.setNoBreak (0);
 ckey.begin();
 if (debug) {
  Serial.begin( 9600 );
  Serial.println("Startup..");
 }

}

void loop() {
  if ( keyboard.available() )
  {
    amskey(keyboard.read());  
  }
}

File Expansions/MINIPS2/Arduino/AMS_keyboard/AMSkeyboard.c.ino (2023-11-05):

/*
  AMSkeyboard - Amstrad Keyboard Library
  Adapted by Ian Cudlip

  Based on C64keyboard - Commodore Keyboard library by Hartland PC LLC
  Copyright (c) 2022 Hartland PC LLC
  Written by Robert VanHazinga

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
  You should have received a copy of the GNU Lesser General Public
  License along with this library; if not, write to the Free Software
  Foundation, Inc., 51 Franklin St, Fifth Floor, Boston, MA  02110-1301  USA
*/
#include "AMSkeyboard.h"

void resetMT88(void) {
  digitalWrite(ANALOG_SW_DATA , LOW);
  digitalWrite(ANALOG_SW_RESET, HIGH);
  digitalWrite( ANALOG_SW_STROBE, HIGH);
  digitalWrite(ANALOG_SW_RESET, LOW);
  digitalWrite( ANALOG_SW_STROBE, LOW);
  digitalWrite(ANALOG_SW_DATA , HIGH);
  keyboard.setLock (PS2_LOCK_SCROLL && 0);
  amsbreak = false;
  capslock = false;
  lshift = false;
  rshift = false;
  currkeymap = 1;
  }

void setswitch(uint8_t c){
  int bitr;
  bool state;
  
  // Fix logic table hole in MT8812/16 and things
  // AX3 line control
  if (!MT8808) {
   if ( (c > 55 && c < 64) || (c > 23 && c < 32 ) || (c > 71 && c < 80)) {
      c -= 24;
      digitalWrite(ANALOG_SW_AX3, HIGH);
   } else {
    if (c > 63 && c < 72) {
       c -= 48;
       digitalWrite(ANALOG_SW_AX3, HIGH);
    }
   }
  }
  
  if (c < 80) {
    for ( int currentPin = ANALOG_SW_ARRAY_START; currentPin <= ANALOG_SW_ARRAY_END; ++currentPin) {
      bitr = (currentPin - ANALOG_SW_ARRAY_START);
      state =  bitRead(c, bitr);
      digitalWrite(currentPin, state);
    }
    digitalWrite( ANALOG_SW_STROBE, HIGH);
    digitalWrite( ANALOG_SW_STROBE, LOW);
  }
  if (!MT8808){digitalWrite(ANALOG_SW_AX3, LOW);}

}

void debugkey (uint8_t c,uint8_t flags,uint8_t kc){
    Serial.print ("AMSTRAD Keycode: ");
    Serial.print (c);
    Serial.print ("  (ASCII Code: ");
    Serial.print (kc);
    Serial.print (" Hex: ");
    Serial.print (kc, HEX);
    Serial.print (")  Flags: ");
      for (int i = 7; i >= 0; i--)
    {
        bool b = bitRead(flags, i);
        Serial.print(b);
    }
    Serial.println();
  }
    
void amskey(uint16_t k) {
   flags = k >> 8;
   uint8_t kc= k & 0xFF;
   uint8_t c = 0;

  if (currkeymap == 2) {
    if (bitRead(flags, 6)) {
      c = pgm_read_byte(keymap->shift_2 + kc);
    }
    else {
      c = pgm_read_byte(keymap->noshift_2 + kc);
    }
  }

   if (currkeymap == 1) {
    if (bitRead(flags, 6)) {
      c = pgm_read_byte(keymap->shift_1 + kc);
    }
    else {
      c = pgm_read_byte(keymap->noshift_1 + kc);
    }
  }
  
//  debug output
    if (debug){debugkey(c,flags,kc);}

// Ignore extended codes 
    if (kc == 250){c=IGNORE_KEYCODE;}
    
// MT reset function    
    if (kc == MT_RESET) {
    resetMT88();  
    c=IGNORE_KEYCODE;
   }   
   
  // AMS Break Key
  if (kc == AMSBREAK) {
     if (bitRead(flags, 7)) {
      amsbreak = false;
      digitalWrite(AMSBREAK_PIN, LOW);
      if (debug) {
        Serial.println("Break Off");
      }
    } else {
      amsbreak = true;
      digitalWrite(AMSBREAK_PIN, HIGH);
      if (debug) {
        Serial.println("Break On");
      }
    }
    c = IGNORE_KEYCODE;
  }
     
// Capslock function 
    if (kc == CAPSLOCK_KEY) {
      capslock = !capslock;
      digitalWrite (ANALOG_SW_DATA, capslock);
      setswitch(AMSLSHFT);
      c = IGNORE_KEYCODE; 
      }

// Keymap Handling
    if (kc == KEY_MAP_1 && !bitRead(flags,7)){
      currkeymap = 1;
      keyboard.setLock (PS2_LOCK_SCROLL && 0);
      }

    if (kc == KEY_MAP_2 && !bitRead(flags,7)){
      currkeymap = 2;
      keyboard.setLock (PS2_LOCK_SCROLL && 1);
      }
        
// Jump to end if key code is an ignored key
    if (c != IGNORE_KEYCODE) {
    // Differential shift conversion during key press
   if (c >= 80 ) {
      c -= 80;
      if (rshift || lshift) {
        //digitalWrite (ANALOG_SW_DATA, LOW);
        //setswitch(AMSRSHFT);      (lets not set the right shift, as for some reasons enter gets pressed)
        digitalWrite (ANALOG_SW_DATA, LOW);
        setswitch(AMSLSHFT);   
      }
      
     else {
        digitalWrite (ANALOG_SW_DATA, HIGH);
        setswitch(AMSLSHFT);
      }
      // Set cross switch key
      digitalWrite(ANALOG_SW_DATA, HIGH);
      setswitch(c);
       if bitRead (flags,7){
      // Restore shift state to match keystate
      digitalWrite (ANALOG_SW_DATA, lshift);
      setswitch(AMSLSHFT);
//      digitalWrite (ANALOG_SW_DATA, rshift);
//      setswitch(AMSRSHFT);
      digitalWrite(ANALOG_SW_DATA, HIGH);
     }
   }
   
// Shift key handling
     if bitRead (flags,6){
      if (c == AMSRSHFT) {rshift = true;}
      if (c == AMSLSHFT) {lshift = true;}
      }
  
    if bitRead (flags,7){
      digitalWrite(ANALOG_SW_DATA , LOW);
        if (c==AMSRSHFT) {rshift = false;}
        if (c==AMSLSHFT) {lshift = false;}
        }

  // Process normal keypress
    if (c != IGNORE_KEYCODE){setswitch(c);}      
 }

// Reset switch state pin to default high state (Key press).
    digitalWrite(ANALOG_SW_DATA , HIGH);
}
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

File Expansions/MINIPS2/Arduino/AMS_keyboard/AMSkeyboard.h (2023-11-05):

/*
  AMSkeyboard - Amstrad Keyboard Library
  Adapted by Ian Cudlip

  Based on C64keyboard - Commodore Keyboard library by Hartland PC LLC
  Copyright (c) 2022 Hartland PC LLC
  Written by Robert VanHazinga

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
  You should have received a copy of the GNU Lesser General Public
  License along with this library; if not, write to the Free Software
  Foundation, Inc., 51 Franklin St, Fifth Floor, Boston, MA  02110-1301  USA
*/

#ifndef AMSkeyboard_h
#define AMSkeyboard_h

#if defined(ARDUINO) && ARDUINO >= 100
#include "Arduino.h"
#else
#include "WProgram.h"
#endif
#define AMS_KEYMAP_SIZE 	   152 // Size of each array in the key maps

#define CPC464  true     // Set true for CPC464, false for legacy 6128 interface.

#include "keymapping.h"

#define debug   false    // Set true for serial monitor of AMS keycodes and PS/2 keycodes

#define MT8808  false    // This has to be set to false now as we use more lines than the MT8808 provides

//PS2 communication pins
#define DATA_PIN				12 // Data pin for PS2 keyboard
#define IRQ_PIN					3  // Interrupt pin for PS2 keyboard

//Scan code value to enable a key map. Default is key map 1.
#define KEY_MAP_1				0x6B // F11?
#define KEY_MAP_2				0x6C // F12?

//Key map value to ignore key press
#define IGNORE_KEYCODE			0xAA //(DEC 170) (Must be > 128)

// Key map value to reset the MT88xx chip
#define MT_RESET        0x6C // (DEC 108) F12 activates MT88XX reset

//MT88xx control pins
#define ANALOG_SW_DATA      2 // Sets selected cross switch on/off (Old 13)
#define ANALOG_SW_STROBE    4 // Strobe timing pulse
#define ANALOG_SW_RESET     13 // Reset all MT88XX cross switches to off (Old 2)
#define ANALOG_SW_ARRAY_START 5 // First pin of 6 bit switch addressing. AY2-0 & AX2-0
#define ANALOG_SW_ARRAY_END   10 // Last pin of 6 bit switch addressing. AY2-0 & AX2-0
#define ANALOG_SW_AX3     11 // Pin that controls AX3 (MT8812 & MT8816) 

//AMS Break Key
#define AMSBREAK_PIN    A0

// Key map value for capslock
#define CAPSLOCK_KEY    0x03 // (DEC 3) CapsLock key 

#define AMSLSHFT  29
#define AMSRSHFT  29

#define AMSBREAK  4

class AMSkeyboard {
  public:
    AMSkeyboard();
    
    static void begin(const AMSKeymap_t &map = AMSKeymap_main);
};
#endif

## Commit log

2023-11-05 Initial Push
    [CPC464-2MINI-B_Cu.gbr, CPC464-2MINI-B_Mask.gbr, CPC464-2MINI-B_Paste.gbr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]
2023-11-05 Readme Updates and 40007 Adapter
    [CPC-40007AdapterLM1117-B_Cu.gbr, CPC-40007AdapterLM1117-B_Mask.gbr, CPC-40007AdapterLM1117-B_Paste.gbr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]
